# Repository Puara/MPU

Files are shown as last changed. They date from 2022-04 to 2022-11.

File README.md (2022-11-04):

# Media processing Unit (MPU)

The Media Processing Unit, or MPU (former SPU) is the core of the [Puara](https://github.com/Puara) framework: it is responsible to receive sensor data from all connected controllers, mapping devices, and running embedded synthesis processes.

This project is developed and maintained in a partnership between [SAT/Metalab](https://sat.qc.ca/fr/recherche/metalab) and [IDMIL](http://www-new.idmil.org/).

[Media Processing Unit - user guide](./docs/MPU_user_guide.md)

## Building instructions

[Media Processing Unit (MPU) - hardware](./building_instructions_hardware.md)

[Media Processing Unit (MPU) - OS](./building_instructions_os.md)

Alternatively, you can download the MPU OS image to use in any Raspberry Pi.
There's no need to reproduce the hardware of the MPU.

The image can be downloaded in the [Releases](https://gitlab.com/sat-mtl/distribution/rpi-images/-/releases) section](https://gitlab.com/sat-mtl/distribution/rpi-images/-/releases) of the [SAT/Metalab](https://sat.qc.ca/fr/recherche/metalab) maintained [project repository](https://gitlab.com/sat-mtl/distribution/rpi-images).

### More Info

[https://www.edumeneses.com](https://www.edumeneses.com)

[http://www-new.idmil.org/project/guitarami/](http://www-new.idmil.org/project/guitarami/)

## Licensing

The code in this project is licensed under the MIT license, unless otherwise specified within the file.

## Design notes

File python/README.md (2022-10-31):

# MPU LCD + buttons setup (GuitarAMI version)

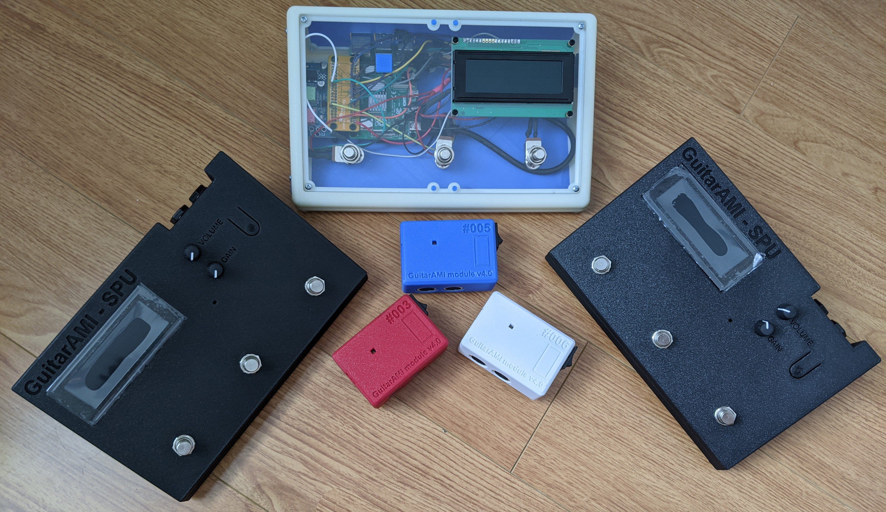
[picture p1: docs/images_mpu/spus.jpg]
MPUs


Instruction on how to build the GuitarAMI MPU can be found in the [Media](./building_instructions_hardware.md) Processing Unit (MPU) - hardware](./building_instructions_hardware.md) guide.

## Set LCD

```bash
sudo apt install python3-rpi.gpio
sudo pip3 install osc4py3
cat <<- "EOF" | sudo tee /lib/systemd/system/lcd.service

[Unit]
Description=OSC to LCD
After=multi-user.target

[Service]
User=mpu
Type=idle
ExecStart=python /home/mpu/sources/MPU/python/lcd.py

[Install]
WantedBy=multi-user.target
EOF
sudo systemctl daemon-reload
sudo systemctl enable --now lcd.service
```

- To send messages to the LCD use `/lcd message 0 0`, sent to port 20000. The first number represents the line and the second the column. Example using oscsend: `oscsend 127.0.0.1 20000 /lcd sii test_message 2 1`
- Sending `/lcd clear 0 0` will clean the LCD

## Set buttons to work

[https://raspberrypihq.com/use-a-push-button-with-raspberry-pi-gpio/](https://raspberrypihq.com/use-a-push-button-with-raspberry-pi-gpio/)

```bash
sudo apt install python3-rpi.gpio python3-gpiozero
sudo pip3 install osc4py3
cat <<- "EOF" | sudo tee /lib/systemd/system/buttonOSC.service
[Unit]
Description=Button to OSC Python3 code
After=multi-user.target

[Service]
User=mpu
Type=idle
ExecStart=python /home/mpu/sources/MPU/python/buttonOSC.py

[Install]
WantedBy=multi-user.target
EOF
sudo systemctl daemon-reload
sudo systemctl enable --now buttonOSC.service
```

## Set status bar

```bash
cat <<- "EOF" | sudo tee /lib/systemd/system/status.service
[Unit]
Description=Status bar OSC Python3 code
After=multi-user.target

[Service]
User=mpu
Type=idle
ExecStart=python /home/mpu/sources/MPU/python/status.py

[Install]
WantedBy=multi-user.target
EOF
sudo systemctl daemon-reload
sudo systemctl enable --now status.service
```

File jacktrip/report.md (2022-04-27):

# JackTrip tests - Brams/IDMIL/uToronto journal

Report in progress used on the JackTrip tests and hardware assembly using the GuitarAMI MPU hardware for the SingWell partnership.

## Schedule

- [X] [First project meeting](#october-14th-2021).
- [X] Duplicate the existing setup (MPU + JackTrip) and automatically set one as a client and another as a server (Oct. 18-22nd, 2021).
- [X] [Latency tests](#october-28th-2021) between the 2 MPUs in a local network on Brams (Oct. 28th, 2021).
- [X] [Latency measurements](#local-network-latency-results) between the 2 MPUs in a local network using jack-delay (Nov. 2nd to 4th, 2021).
- [X] Test internet latency between the 2 MPUs. One MPU will be located at Brams and another at IDMIL (or close location nearby). We will need IT on both universities to fully open UDP communication at port 4464, and we'll probably need to set a VPN between both institutions (TBD, probably Nov. 5th, 2021).
- [X] Define audio interface for the SingWell MPUs ([Focusrite Scarlett Solo](https://focusrite.com/en/audio-interface/scarlett/scarlett-solo)).
- [X] Build 2 MPUs for the project (late November 2021).
- [ ] Final tests at UdeM (second week of December 2021).

## October 14th, 2021

Meeting summary:

- We successfully ran JackTrip on the GuitarAMI Sound Processing Unit (MPU). The MPU acted as a server, and we could connect a laptop also running JackTrip and a client.
- The MPU is capable of serving JackTrip, synthesize sounds, or share audio through the network.
- Start discussing next week the strategies to communicate between UdeM and McGill.

## October 28th, 2021

- Preliminary tests on Brams using two [GuitarAMI MPUs](https://github.com/edumeneses/GuitarAMI/blob/jacktrip/docs/MPU_user_guide.md). Setup worked using a local network, the MPUs, and a laptop used to interact with the machines.

## Local network latency results

- Loopback latency using the built-in interface [Pisound](https://blokas.io/pisound/):
  - Jack configuration: 48000Hz (sample rate), 128 samples (buffer size), 2 period
    - Average latency MPU003: 8.921 ms
    - Average latency MPU005: 8.924 ms

- Latency bettween 2 MPUs (local network) using the built-in interface [Pisound](https://blokas.io/pisound/):
  - Test 1 - Jack configuration: 48000Hz (sample rate), 128 samples (buffer size), 2 period
    - Average latency: 30.256 ms
  - Test 2 - Jack configuration: 96000Hz (sample rate), 128 samples (buffer size), 2 period
    - Average latency: 13.125 ms
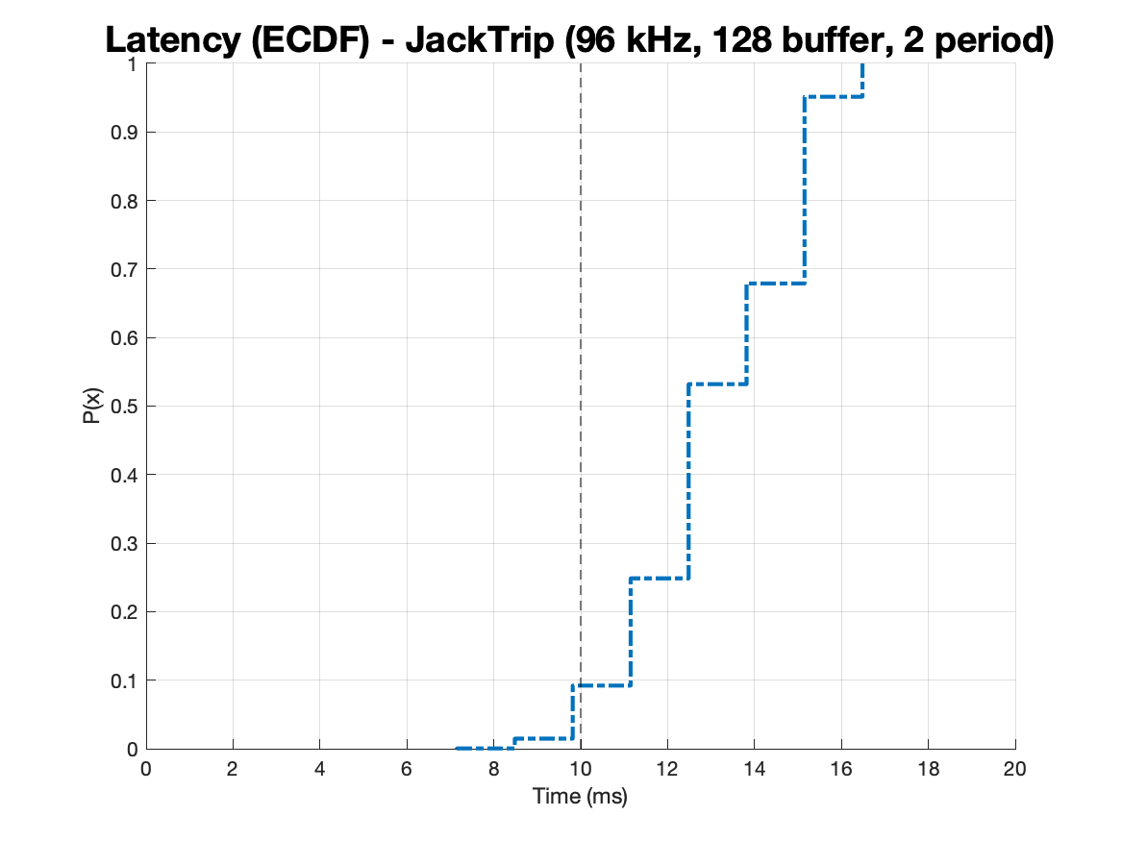
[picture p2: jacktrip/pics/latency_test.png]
Latency (ECDF) - JackTrip (96 kHz, 128 buffer, 2 period)
    - ECDF: 

- Latency bettween 2 MPUs (local network) using the [Presonus AudioBox USB](https://www.presonus.com/products/audiobox-usb) for 48 kHz and [Motu Ultra Lite  mk4](https://motu.com/en-us/news/introducing-the-ultralite-mk4/) for 96 kHz on the client end:
  - Test 3 - Jack configuration: 48000Hz (sample rate), 128 samples (buffer size), 2 period
    - Average latency: 29.645 ms
  - Test 4 - Jack configuration: 96000Hz (sample rate), 128 samples (buffer size), 2 period
    - Average latency: 17.617 ms

Results Summary:

| Description | Sample rate | Average latency |
| --- | --- | --- |
| Loopback | 48 kHz | 8.923 ms |
| JackTrip with Pisound | 48 kHz | 30.256 ms |
| JackTrip with Pisound | 96 kHz | 13.125 ms |
| JackTrip with USB audio | 48 kHz | 29.645 ms |
| JackTrip with USB audio | 96 kHz | 17.617 ms |

## Latency tests with the final JackTrip boxes + Focusrite Scarlett Solo

- Jack configuration: 96000Hz (sample rate), 128 samples (buffer size), 3 period
  - Average latency: 19.366 ms (1859.152 frames)

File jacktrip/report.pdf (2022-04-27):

report.md | 12/3/2021

1 / 2

# JackTrip tests - Brams/IDMIL/uToronto journal

Report in progress used on the JackTrip tests and hardware assembly using the GuitarAMI SPU hardware for the SingWell partnership.

## Schedule

First project meeting.
Duplicate the existing setup (SPU + JackTrip) and automatically set one as a client and another as a server (Oct. 18-22nd, 2021).
Latency tests between the 2 SPUs in a local network on Brams (Oct. 28th, 2021).
Latency measurements between the 2 SPUs in a local network using jack-delay (Nov. 2nd to 4th, 2021).
Test internet latency between the 2 SPUs. One SPU will be located at Brams and another at IDMIL (or close location nearby). We will need IT on both universities to fully open UDP communication at port 4464, and we'll probably need to set a VPN between both institutions (TBD, probably Nov. 5th, 2021).
Define audio interface for the SingWell SPUs (Focusrite Scarlett Solo). (https://focusrite.com/en/audio-interface/scarlett/scarlett-solo)
Build 2 SPUs for the project (late November 2021).
Final tests at UdeM (second week of December 2021).

## October 14th, 2021

Meeting summary:

We successfully ran JackTrip on the GuitarAMI Sound Processing Unit (SPU). The SPU acted as a server, and we could connect a laptop also running JackTrip and a client.
The SPU is capable of serving JackTrip, synthesize sounds, or share audio through the network. Start discussing next week the strategies to communicate between UdeM and McGill.

## October 28th, 2021

Preliminary tests on Brams using two GuitarAMI SPUs. (https://github.com/edumeneses/GuitarAMI/blob/jacktrip/docs/SPU_user_guide.md) Setup worked using a local network, the SPUs, and a laptop used to interact with the machines.

## Local network latency results

Loopback latency using the built-in interface Pisound: (https://blokas.io/pisound/)

Jack configuration: 48000Hz (sample rate), 128 samples (buffer size), 2 period Average latency SPU003: 8.921 ms
Average latency SPU005: 8.924 ms

Latency bettween 2 SPUs (local network) using the built-in interface Pisound: (https://blokas.io/pisound/)

Test 1 - Jack configuration: 48000Hz (sample rate), 128 samples (buffer size), 2 period Average latency: 30.256 ms
Test 2 - Jack configuration: 96000Hz (sample rate), 128 samples (buffer size), 2 period

report.md | 12/3/2021

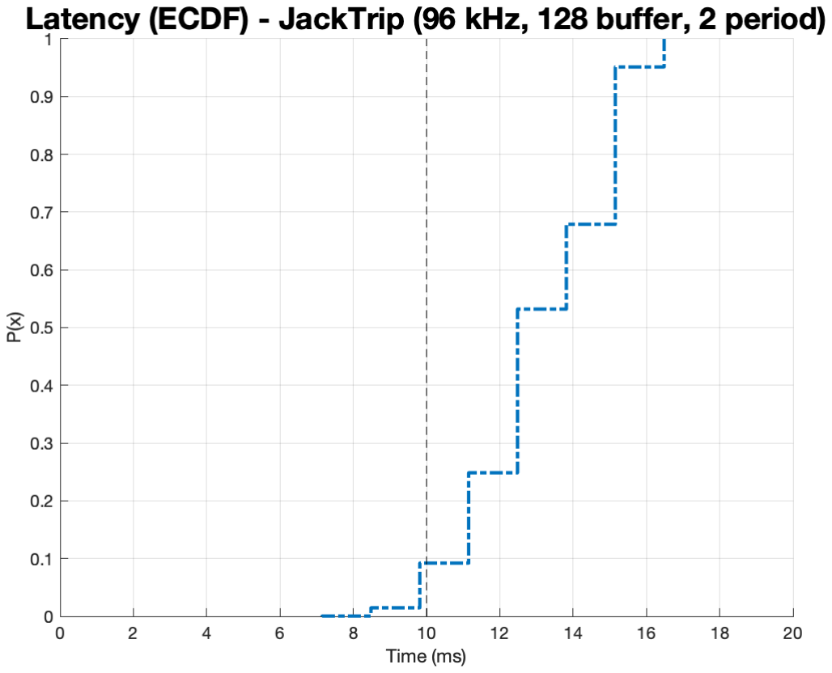
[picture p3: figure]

2 / 2

Average latency: 13.125 ms ECDF:

Latency bettween 2 SPUs (local network) using the Presonus AudioBox USB (https://www.presonus.com/products/audiobox-usb) for 48 kHz and Motu Ultra Lite mk4 for 96 kHz on the client end: (https://motu.com/en-us/news/introducing-the-ultralite-mk4/)

Test 3 - Jack configuration: 48000Hz (sample rate), 128 samples (buffer size), 2 period Average latency: 29.645 ms
Test 4 - Jack configuration: 96000Hz (sample rate), 128 samples (buffer size), 2 period Average latency: 17.617 ms

Results Summary:

Description | Sample rate | Average latency
Loopback | 48 kHz | 8.923 ms
JackTrip with Pisound | 48 kHz | 30.256 ms
JackTrip with Pisound | 96 kHz | 13.125 ms
JackTrip with USB audio | 48 kHz | 29.645 ms
JackTrip with USB audio | 96 kHz | 17.617 ms

## Latency tests with the final JackTrip boxes + Focusrite Scarlett Solo

Jack configuration: 96000Hz (sample rate), 128 samples (buffer size), 3 period
Average latency: 19.366 ms (1859.152 frames)

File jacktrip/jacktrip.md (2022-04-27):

# JackTrip tests on MPU

Official information on building JackTrip on Rpi4 available at [https://help.jacktrip.org/hc/en-us/articles/1500009727561-Build-a-Raspberry-Pi-4B-Computer-with-JackTrip](https://help.jacktrip.org/hc/en-us/articles/1500009727561-Build-a-Raspberry-Pi-4B-Computer-with-JackTrip)

## Compiling and running JackTrip headless on the MPU

- Dependencies: `sudo apt install libjack-jackd2-dev librtaudio-dev qt5-default`
- Extra package to test latency: `sudo apt install -y jack-delay`
- cloning and building JackTrip:

    ```bash
    cd ~/sources
    git clone https://github.com/jacktrip/jacktrip.git
    cd ~/sources/jacktrip/src
    ./build
    export JACK_NO_AUDIO_RESERVATION=1
    ```

## To manually use as a client

- with IP address: `./jacktrip -c [xxx.xx.xxx.xxx]`
- with name: `./jacktrip -c mpuXXX.local`

## Adding a service to start JackTrip server

OBS: client name is the name of the other machine

```bash
cat <<- "EOF" | tee ~/.config/systemd/user/jacktrip_server.service
[Unit]
Description=Run JackTrip server
After=multi-user.target

[Service]
Type=idle
Restart=always
ExecStart=/home/patch/sources/jacktrip/builddir/jacktrip -s --clientname mpu005.local

[Install]
WantedBy=default.target
EOF
```

```bash
sudo chmod 644 ~/.config/systemd/user/jacktrip_server.service
systemctl --user daemon-reload
systemctl --user enable jacktrip_server.service
```

## Adding a service to start JackTrip client (in this example, the server is mpu003.local)

```bash
cat <<- "EOF" | tee ~/.config/systemd/user/jacktrip_client.service
[Unit]
Description=Run JackTrip client
After=multi-user.target

[Service]
Type=idle
Restart=always
ExecStart=/home/patch/sources/jacktrip/builddir/jacktrip -c mpu003.local --clientname mpu005.local

[Install]
WantedBy=default.target
EOF
```

```bash
sudo chmod 644 ~/.config/systemd/user/jacktrip_client.service
systemctl --user daemon-reload
systemctl --user enable jacktrip_client.service
```

## Install aj-snapshot

[http://aj-snapshot.sourceforge.net/](http://aj-snapshot.sourceforge.net/)

Check the last version on the website

```bash
sudo apt install -y libmxml-dev &&\
cd ~/sources &&\
wget http://downloads.sourceforge.net/project/aj-snapshot/aj-snapshot-0.9.9.tar.bz2 &&\
tar -xvjf aj-snapshot-0.9.9.tar.bz2 &&\
cd aj-snapshot-0.9.9 &&\
./configure &&\
make &&\
sudo make install
```

- To create a snapshot: `aj-snapshot -f ~/Documents/default.connections`
- To remove all Jack connections: `aj-snapshot -xj`
- To save connections: `sudo aj-snapshot -f ~/Documents/default.connections`
- To restore connections: `sudo aj-snapshot -r ~/Documents/default.connections`

Set the Jack connections to load at boot:

```bash
cat <<- "EOF" | sudo tee /lib/systemd/system/ajsnapshot.service
[Unit]
Description=AJ-Snapshot
After=sound.target jackaudio.service

[Service]
Type=oneshot
ExecStart=/usr/local/bin/aj-snapshot -r ~/Documents/default.connections

[Install]
WantedBy=multi-user.target
EOF
```

```bash
sudo systemctl daemon-reload &&\
sudo systemctl enable ajsnapshot.service
```

## Mapping using jack in CLI

- Check available devices: `cat /proc/asound/cards`. If you have multiple devices available, can call them by name
- lists jack available ports: `jack_lsp`
- List informtion and connections on ports: `jack_lsp -c` or `jack_lsp -A`
- Connect ports: `jack_connect [ -s | --server servername ] [-h | --help ] port1 port2` (The exit status is zero if successful, 1 otherwise)
- Disconnect ports: `jack_disconnect [ -s | --server servername ] [ -h | --help ] port1 port2`

## Latency tests

Make sure JackTrip is running.

- Connect the necessary audio cable to create a loopback on the audio interface (audio OUT -> audio IN)
- Remove all Jack connections of both machines: `aj-snapshot -xj`
- For the loopback (same interface test): `jack_delay -I system:capture_2 -O system:playback_2`
- For JackTrip (jack_delay running on the server):
  - on the server:
    - `jack_connect system:playback_2 mpu005.local:receive_2`
    - `jack_connect system:capture_2 mpu005.local:send_2`
  - on the client:
    - `jack_connect system:playback_2 mpu003:receive_2`
    - `jack_connect system:capture_2 mpu003:send_2`
- run the test: `jack_delay -O mpu005.local:send_2 -I mpu005.local:receive_2`

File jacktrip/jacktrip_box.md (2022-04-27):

# JackTrip box recipe

- [JackTrip box recipe](#jacktrip-box-recipe)
  - [Hardware](#hardware)
  - [Prepare PatchboxOS](#prepare-patchboxos)
  - [Finish PatchboxOS config](#finish-patchboxos-config)
  - [Compiling and running JackTrip headless on the MPU](#compiling-and-running-jacktrip-headless-on-the-mpu)
  - [To manually use as a client](#to-manually-use-as-a-client)
  - [Adding a service to start JackTrip server](#adding-a-service-to-start-jacktrip-server)
  - [Adding a service to start JackTrip client (in this example, the server is mpu003.local)](#adding-a-service-to-start-jacktrip-client-in-this-example-the-server-is-mpu003local)
  - [Install aj-snapshot](#install-aj-snapshot)
  - [Mapping using jack in CLI](#mapping-using-jack-in-cli)
  - [Latency tests](#latency-tests)
  - [Jack available commands](#jack-available-commands)
  - [Mosquitto MTQQ server (for messaging)](#mosquitto-mtqq-server-for-messaging)
  - [Places to change the MPU name when cloning the SD](#places-to-change-the-mpu-name-when-cloning-the-sd)
  - [Setting the server IP at the client box](#setting-the-server-ip-at-the-client-box)

## Hardware

- Raspberry Pi 4 B with heatsinks and fan (optional)
- Rpi case
- Power supply
- SD card (min 8 GB)
- USB audio interface (recommended: Focusrite Scarlett Solo)

Official information on building JackTrip on Rpi4 is available at [https://help.jacktrip.org/hc/en-us/articles/1500009727561-Build-a-Raspberry-Pi-4B-Computer-with-JackTrip](https://help.jacktrip.org/hc/en-us/articles/1500009727561-Build-a-Raspberry-Pi-4B-Computer-with-JackTrip)

## Prepare PatchboxOS

- Download the [PatchboxOS](https://blokas.io/patchbox-os/#patchbox-os-download)
- Flash the image using [ApplePiBaker](https://www.tweaking4all.com/hardware/raspberry-pi/applepi-baker-v2/), [balenaEtcher](https://www.balena.io/etcher/), or diskutil (dd)
- Connect the audio interface
- Boot the Rpi and folow the [first run tutorial](https://blokas.io/patchbox-os/docs/first-run-options/)
  - ssh to th MPU: `ssh patch@ip_address` (The default user name is *patch* and its password is *blokaslabs*). Use ethernet (wired) connection.
    - update PatchBox
    - set new password: `mappings` or orther password of choice
    - choose default soundcard: USB, 48000, 128, 3
    - select boot: *console*
    - connect to network: *no*
    - choose module: *none*

## Finish PatchboxOS config

- Update system:
  - `sudo apt update`
  - `sudo apt upgrade`
- Enter PiSound configuration: `sudo pisound-config`
  - Update Pisound
  - Change Pisound HotSpot settings:
    - ssid: `jacktrip00X` (use chosen ID)
    - wpa_passphrase: `mappings` (or anothe password of choice)
- Enter Raspi-Config: `sudo raspi-config`
  - Update:
    - `Update this tool to the latest version`
  - System options:
    - Hostname: `jacktrip00X` (use MPU's ID)
  - Advanced options:
    - expand filesystem

Create a place for source codes: `mkdir ~/sources`

Create a place for the user systemd services: `mkdir -p ~/.config/systemd/user`

Reboot

## Compiling and running JackTrip headless on the MPU

- Dependencies: `sudo apt install libjack-jackd2-dev librtaudio-dev qt5-default`
- Extra package to test latency: `sudo apt install -y jack-delay`
- cloning and building JackTrip:

    ```bash
    cd ~/sources
    git clone https://github.com/jacktrip/jacktrip.git
    cd ~/sources/jacktrip
    ./build
    export JACK_NO_AUDIO_RESERVATION=1
    ```

## To manually use as a client

- with IP address: `./jacktrip -c [xxx.xx.xxx.xxx]`
- with name: `./jacktrip -c mpuXXX.local`

## Adding a service to start JackTrip server

OBS: client name is the name of the other machine

```bash
cat <<- "EOF" | tee ~/.config/systemd/user/jacktrip_server.service
[Unit]
Description=Run JackTrip server
After=multi-user.target

[Service]
Type=idle
Restart=always
ExecStart=/home/patch/sources/jacktrip/builddir/jacktrip -s --clientname jacktrip_client

[Install]
WantedBy=default.target
EOF
```

```bash
sudo chmod 644 ~/.config/systemd/user/jacktrip_server.service
systemctl --user daemon-reload
systemctl --user enable jacktrip_server.service
```

## Adding a service to start JackTrip client (in this example, the server is mpu003.local)

Replace the IP address for the server IP.

```bash
cat <<- "EOF" | tee ~/.config/systemd/user/jacktrip_client.service
[Unit]
Description=Run JackTrip client
After=multi-user.target

[Service]
Type=idle
Restart=always
ExecStart=/home/patch/sources/jacktrip/builddir/jacktrip -c 192.168.1.1 --clientname jacktrip_client

[Install]
WantedBy=default.target
EOF
```

```bash
sudo chmod 644 ~/.config/systemd/user/jacktrip_client.service
systemctl --user daemon-reload
```

If you want to enable the client, disable the service and run `systemctl --user enable jacktrip_client.service`

## Install aj-snapshot

[http://aj-snapshot.sourceforge.net/](http://aj-snapshot.sourceforge.net/)

Check the last version on the website

```bash
sudo apt install -y libmxml-dev &&\
cd ~/sources &&\
wget http://downloads.sourceforge.net/project/aj-snapshot/aj-snapshot-0.9.9.tar.bz2 &&\
tar -xvjf aj-snapshot-0.9.9.tar.bz2 &&\
cd aj-snapshot-0.9.9 &&\
./configure &&\
make &&\
sudo make install
```

- To create a snapshot: `aj-snapshot -f ~/Documents/default.connections`
- To remove all Jack connections: `aj-snapshot -xj`
- To save connections: `sudo aj-snapshot -f ~/Documents/default.connections`
- To restore connections: `sudo aj-snapshot -r ~/Documents/default.connections`

Set custom Jack connections to load at boot:

```bash
cat <<- "EOF" | sudo tee /lib/systemd/system/ajsnapshot.service
[Unit]
Description=AJ-Snapshot
After=sound.target jackaudio.service

[Service]
Type=oneshot
ExecStart=/usr/local/bin/aj-snapshot -r ~/Documents/default.connections

[Install]
WantedBy=multi-user.target
EOF
```

```bash
sudo systemctl daemon-reload &&\
sudo systemctl enable ajsnapshot.service
```

## Mapping using jack in CLI

- Check available devices: `cat /proc/asound/cards`. If you have multiple devices available, can call them by name
- lists jack available ports: `jack_lsp`
- List informtion and connections on ports: `jack_lsp -c` or `jack_lsp -A`
- Connect ports: `jack_connect [ -s | --server servername ] [-h | --help ] port1 port2` (The exit status is zero if successful, 1 otherwise)
- Disconnect ports: `jack_disconnect [ -s | --server servername ] [ -h | --help ] port1 port2`

## Latency tests

Make sure JackTrip is running.

- Connect the necessary audio cable to create a loopback on the client's audio interface (audio OUT -> audio IN)
- For the loopback (same interface test): `jack_delay -I system:capture_2 -O system:playback_2`
- run the test: `jack_delay -O jacktrip_client.local:send_2 -I jacktrip_client.local:receive_2`

## Jack available commands

To get a list on the computer, type **jack** and hit *Tab*

|command |command |command |command |command |
|---|---|---|---|---|
| jack_alias | jack_bufsize | jack_capture | jack_capture_gui | jack_connect |
| jackdbus | jack_disconnect | jack-dl | jack-dssi-host | jack_evmon |
| jack_load | jack_lsp | jack_metro | jack_midi_dump | jack_midi_latency_test |
| jack_net_master | jack_net_slave | jack_netsource | jack-osc | jack-play |
| jack_samplerate | jack-scope | jack_server_control | jack_session_notify | jack_showtime |
| jack_thru | jack_transport | jack-transport | jack-udp | jack_unload |
| jack_control | jack_cpu | jack_cpu_load | jackd | jack_wait |
| jack_freewheel  | jack_iodelay | jack-keyboard | jack_latent_client  | jack_midiseq |
| jack_midisine | jack_monitor_client | jack_multiple_metro | jack-plumbing |
| jack-rack | jack_rec | jack-record | jack_test |
| jack_simdtests  | jack_simple_client  | jack_simple_session_client | jack_zombie |

To check Jack logs: `sudo journalctl -u jack.service`

## Mosquitto MTQQ server (for messaging)

Install Mosquitto: `sudo apt install -y mosquitto mosquitto-clients`

Set both client and server to listen to the server's broker: `mosquitto_sub -h jacktrip001.local -t message`

Send periodic messages from each machine:

```bash
cat <<- "EOF" | sudo tee /etc/systemd/system/ping.service
[Unit]
Description=Service for sending ping MTQQ messages
Wants=ping.timer

[Service]
Type=oneshot
ExecStart=sh -c 'mosquitto_pub -h "jacktrip001.local" -t "message" -m "Jacktrip001 is up"'

[Install]
WantedBy=multi-user.target
EOF
```

```bash
cat <<- "EOF" | sudo tee /etc/systemd/system/ping.timer
[Unit]
Description=Service for sending ping MTQQ messages
Requires=ping.service

[Timer]
Unit=ping.service
OnUnitInactiveSec=1s
AccuracySec=1s

[Install]
WantedBy=timers.target
EOF
```

Enable timer

```bash
sudo systemctl daemon-reload
sudo systemctl enable ping.timer
```

## Places to change the MPU name when cloning the SD

- Enter PiSound configuration: `sudo pisound-config`
  - Change Pisound HotSpot settings:
    - ssid: `jacktrip00X` (use MPU's ID)
- Enter Raspi-Config: `sudo raspi-config`
  - System options:
    - Hostname: `jacktrip00X` (use chosen ID)

## Setting the server IP at the client box

- Edit the *jacktrip_client.service* file: `nano ~/.config/systemd/user/jacktrip_client.service`
- Replace the IP at the line `ExecStart=/home/patch/sources/jacktrip/builddir/jacktrip -c 192.168.1.1 --clientname jacktrip_client` for the new IP address
- Save the file (Ctrl+O, then hit ENTER in *nano*) and exit (Ctrl+X in *nano*).
- Edit the *ping.service* file: `sudo nano /etc/systemd/system/ping.service`
- Replace the IP (server name) and the client box name at the line `ExecStart=sh -c 'mosquitto_pub -h "jacktrip001.local" -t "message" -m "Jacktrip002 is up"` for the new IP address and proper client name.
- Save the file (Ctrl+O, then hit ENTER in *nano*) and exit (Ctrl+X in *nano*).
- Update the systemctl daemons: `systemctl --user daemon-reload` and `sudo systemctl daemon-reload`
- Restart the services: `systemctl --user restart jacktrip_client.service` and `sudo systemctl restart ping.timer`
- To check connection (if the server is available and accessible through the given IP): `systemctl --user status jacktrip_client.service`

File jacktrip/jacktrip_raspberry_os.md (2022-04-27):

# JackTrip tests on Raspberry OS

Using Rpi 4B + Raspbian OS + Pisound or USB audio Interface

Official information on building JackTrip on Rpi4 available at [https://help.jacktrip.org/hc/en-us/articles/1500009727561-Build-a-Raspberry-Pi-4B-Computer-with-JackTrip](https://help.jacktrip.org/hc/en-us/articles/1500009727561-Build-a-Raspberry-Pi-4B-Computer-with-JackTrip)

## Prepare SD card

- Download [Raspberry OS](https://www.raspberrypi.com/software/)
- Flash the image using [ApplePiBaker](https://www.tweaking4all.com/hardware/raspberry-pi/applepi-baker-v2/), [balenaEtcher](https://www.balena.io/etcher/), or diskutil (dd)
- Create an ssh file at the SSD boot folder: `touch ssh`
- Create a `wpa_supplicant.conf` file with the following contents (change SSID and password!) and boot the system (Rpi)

    ```bash
    cat <<EOF >wpa_supplicant.conf
        ctrl_interface=DIR=/var/run/wpa_supplicant GROUP=netdev
        update_config=1
        country=CA

        network={
            ssid="your_real_wifi_ssid"
            scan_ssid=1
            psk="your_real_password"
            key_mgmt=WPA-PSK
        }
    EOF
    ```

## First config

- ssh to the Rpi: `ssh pi@ip_address` (The default user name is *pi* and its password is *raspberry*)
- Run `sudo raspi-config`
  - Update
  - Change password (mappings)
  - Change hostmane (MPU001)
  - Set WiFi Country (in system options, Wireless LAN)
  - Set locale (en_CA UTF-8 UTF-8)
  - Set timezone
  - Expand filesystem
- reboot
- Update the system:
  - `sudo apt update`
  - `sudo apt dist-upgrade`
- Install Vim as an optional editor: `sudo apt -y install vim`
- Create some folders: `mkdir ~/sources ~/Documents ~/.config/systemd/ ~/.config/systemd/user`

## Install Jack2

[http://jackaudio.org/faq/build_info.html](http://jackaudio.org/faq/build_info.html)

- Dependencies:
  
  `sudo apt-get install libsamplerate0-dev libsndfile1-dev libasound2-dev libavahi-client-dev libreadline-dev libfftw3-dev libudev-dev libncurses5-dev cmake git`

- compile and install jackd (no d-bus):

    ```bash
    cd ~/sources
    git clone git://github.com/jackaudio/jack2 --depth 1
    cd ~/sources/jack2
    ./waf configure --alsa --libdir=/usr/lib/arm-linux-gnueabihf/
    ./waf build
    sudo ./waf install
    sudo ldconfig
    sudo sh -c "echo @audio - memlock 256000 >> /etc/security/limits.conf"
    sudo sh -c "echo @audio - rtprio 75 >> /etc/security/limits.conf"
    echo /usr/local/bin/jackd -P50 -dalsa -p128 -n2 -r48000 > ~/.jackdrc
    ```

- set Jack to start at boot:

    ```bash
    cat <<- "EOF" | sudo tee /lib/systemd/system/jackaudio.service
    [Unit]
    Description=JACK Audio
    After=sound.target

    [Service]
    ExecStart=jackd -P50 -t2000 -d alsa -d hw:USB -p128 -n2 -r48000 -s &

    [Install]
    WantedBy=multi-user.target
    EOF

    ```

    ```bash
    sudo chmod 644 /lib/systemd/system/jackaudio.service
    sudo systemctl daemon-reload
    sudo systemctl enable jackaudio.service
    sudo systemctl start jackaudio.service
    ```

- Reboot

Some commands:

- Check available devices: `cat /proc/asound/cards`. If you have multiple devices available, can call them by name
- List informtion and connections on ports: `jack_lsp -c`
- Connect ports: `jack_connect [ -s | --server servername ] [-h | --help ] port1 port2` (The exit status is zero if successful, 1 otherwise)
- Disconnect ports: `jack_disconnect [ -s | --server servername ] [ -h | --help ] port1 port2`

## Compiling and running JackTrip headless on the MPU

- Dependencies: `sudo apt install libjack-jackd2-dev librtaudio-dev qt5-default`
- Extra package to test latency: `sudo apt install jack-delay`
- cloning and building JackTrip:

    ```bash
    cd ~/sources
    git clone https://github.com/jacktrip/jacktrip.git
    cd ~/sources/jacktrip/src
    ./build
    export JACK_NO_AUDIO_RESERVATION=1
    ```

## To manually use as a client

- with IP address: `./jacktrip -c [xxx.xx.xxx.xxx]`
- with name: `./jacktrip -c mpuXXX.local`

## Adding a service to start JackTrip server

```bash
cat <<- "EOF" | sudo tee /lib/systemd/system/jacktrip_server.service
[Unit]
Description=Run JackTrip server
After=multi-user.target

[Service]
Type=idle
Restart=always
ExecStart=/home/pi/sources/jacktrip/builddir/jacktrip -s

[Install]
WantedBy=multi-user.target
EOF
```

```bash
sudo chmod 644 /lib/systemd/system/jacktrip_server.service
sudo systemctl daemon-reload
sudo systemctl enable jacktrip_server.service
sudo systemctl start jacktrip_server.service
```

## Adding a service to start JackTrip client (in this example, the server is mpu003.local)

```bash
cat <<- "EOF" | sudo tee /lib/systemd/system/jacktrip_client.service
[Unit]
Description=Run JackTrip client
After=multi-user.target

[Service]
Type=idle
Restart=always
ExecStart=/home/pi/sources/jacktrip/builddir/jacktrip -c mpu005.local

[Install]
WantedBy=multi-user.target
EOF
```

```bash
sudo chmod 644 /lib/systemd/system/jacktrip_client.service
sudo systemctl daemon-reload
sudo systemctl enable jacktrip_client.service
sudo systemctl start jacktrip_client.service
```

## Mapping using jack in CLI

- `jack_lsp`: lists jack available ports
- `jack_lsp -c`: lists jack available ports with connections

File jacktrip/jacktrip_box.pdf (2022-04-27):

jacktrip_box.md | 12/3/2021

# JackTrip box recipe

Hardware Prepare PatchboxOS Finish PatchboxOS config Compiling and running JackTrip headless on the SPU To manually use as a client Adding a service to start JackTrip server Adding a service to start JackTrip client (in this example, the server is spu003.local) Install aj-snapshot Mapping using jack in CLI Latency tests Jack available commands Places to change the SPU name when cloning the SD Setting the server IP at the client box

## Hardware

Raspberry Pi 4 B with heatsinks and fan (optional)
Rpi case
Power supply
SD card (min 8 GB)
USB audio interface (recommended: Focusrite Scarlett Solo)

Official information on building JackTrip on Rpi4 available at https://help.jacktrip.org/hc/en-us/articles/1500009727561-Build-a-Raspberry-Pi-4B-Computer-with-JackTrip (https://help.jacktrip.org/hc/en-us/articles/1500009727561-Build-a-Raspberry-Pi-4B-Computer-with-JackTrip)

## Prepare PatchboxOS

Download the PatchboxOS (https://blokas.io/patchbox-os/#patchbox-os-download)
Flash the image using ApplePiBaker, (https://www.tweaking4all.com/hardware/raspberry-pi/applepi-baker-v2/) balenaEtcher, (https://www.balena.io/etcher/) or diskutil (dd)
Connect the audio interface
Boot the Rpi and folow the first run tutorial (https://blokas.io/patchbox-os/docs/first-run-options/)
ssh to th SPU: ssh patch@ip_address (The default user name is patch and its password is blokaslabs). Use ethernet (wired) connection.
update PatchBox
set new password: mappings or orther password of choice
choose default soundcard: USB, 48000, 128, 3
select boot: console
connect to network: no
choose module: none

## Finish PatchboxOS config

Update system:
sudo apt update
sudo apt upgrade
Enter PiSound configuration: sudo pisound-config Update Pisound
Change Pisound HotSpot settings:
ssid: jacktrip00X (use chosen ID)
wpa_passphrase: mappings (or anothe password of choice) Enter Raspi-Config: sudo raspi-config Update:
Update this tool to the latest version System options:
Hostname: jacktrip00X (use SPU's ID) Advanced options:
expand filesystem

Create a place for source codes: mkdir ~/sources

Create a place for the user systemd services: mkdir -p ~/.config/systemd/user

Reboot

## Compiling and running JackTrip headless on the SPU

Dependencies: sudo apt install libjack-jackd2-dev librtaudio-dev qt5-default

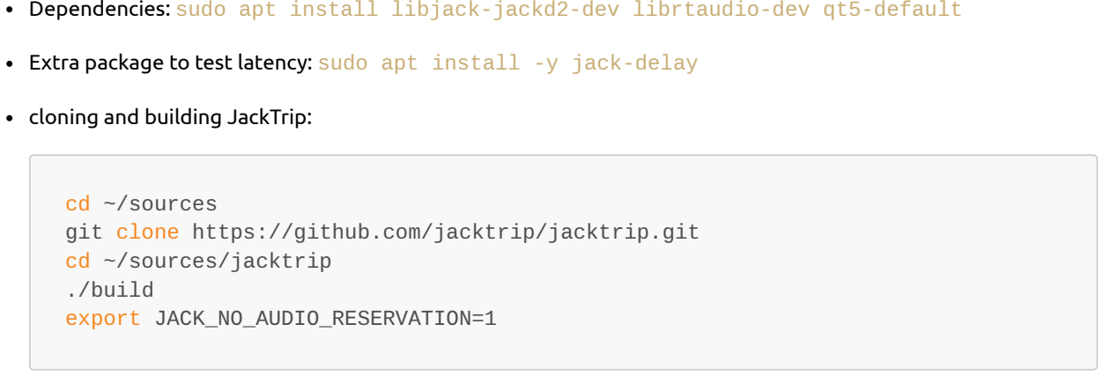
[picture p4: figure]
cloning and building JackTrip:; cd ~/sources git clone https://github.com/jacktrip/jacktrip.git cd ~/sources/jacktrip ./build export JACK_NO_AUDIO_RESERVATION=1

Extra package to test latency: sudo apt install -y jack-delay

## To manually use as a client

with IP address: ./jacktrip -c [xxx.xx.xxx.xxx] with name: ./jacktrip -c spuXXX.local

## Adding a service to start JackTrip server

OBS: client name is the name of the other machine

cat <<- "EOF" | tee ~/.config/systemd/user/jacktrip_server.service
[Unit]
Description=Run JackTrip server
After=multi-user.target

[Service]
Type=idle
Restart=always
ExecStart=/home/patch/sources/jacktrip/builddir/jacktrip -s --clientname jacktrip_client

[Install]
WantedBy=default.target
EOF

sudo chmod 644 ~/.config/systemd/user/jacktrip_server.service systemctl --user daemon-reload
systemctl --user enable jacktrip_server.service

## Adding a service to start JackTrip client (in this example, the server is spu003.local)

Replace the IP address for the server IP.

cat <<- "EOF" | tee ~/.config/systemd/user/jacktrip_client.service
[Unit]
Description=Run JackTrip client
After=multi-user.target

[Service]
Type=idle
Restart=always
ExecStart=/home/patch/sources/jacktrip/builddir/jacktrip -c 192.168.1.1 --clientname jacktrip_client

[Install]
WantedBy=default.target
EOF

If you want to enable the client, disable the service and run systemctl --user enable jacktrip_client.service

## Install aj-snapshot

http://aj-snapshot.sourceforge.net/

Check the last version on the website

sudo apt install -y libmxml-dev &&\
cd ~/sources &&\
wget http://downloads.sourceforge.net/project/aj-snapshot/aj-snapshot-0.9.9.tar.bz2&&\
tar -xvjf aj-snapshot-0.9.9.tar.bz2 &&\
cd aj-snapshot-0.9.9 &&\
./configure &&\
make &&\
sudo make install

To create a snapshot: aj-snapshot -f ~/Documents/default.connections
To remove all Jack connections: aj-snapshot -xj
To save connections: sudo aj-snapshot -f ~/Documents/default.connections To restore connections: sudo aj-snapshot -r ~/Documents/default.connections

Set custom Jack connections to load at boot:

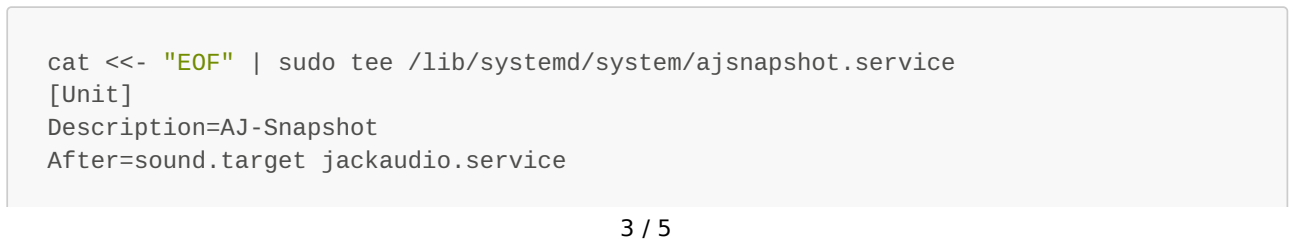
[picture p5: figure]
[Unit] Description=AJ-Snapshot After=sound.target jackaudio.service

cat <<- "EOF" | sudo tee /lib/systemd/system/ajsnapshot.service

[Service]
Type=oneshot
ExecStart=/usr/local/bin/aj-snapshot -r ~/Documents/default.connections

[Install]
WantedBy=multi-user.target
EOF

sudo systemctl daemon-reload &&\
sudo systemctl enable ajsnapshot.service

## Mapping using jack in CLI

Check available devices: cat /proc/asound/cards. If you have multiple devices available, can call them by name
lists jack available ports: jack_lsp
List informtion and connections on ports: jack_lsp -c or jack_lsp -A
Connect ports: jack_connect [ -s | --server servername ] [-h | --help ] port1 port2 (The
exit status is zero if successful, 1 otherwise)
Disconnect ports: jack_disconnect [ -s | --server servername ] [ -h | --help ] port1
port2

## Latency tests

Make sure JackTrip is running.

Connect the necessary audio cable to create a loopback on the client's audio interface (audio OUT -> audio IN) For the loopback (same interface test): jack_delay -I system:capture_2 -O system:playback_2 run the test: jack_delay -O jacktrip_client.local:send_2 -I jacktrip_client.local:receive_2

## Jack available commands

To get a list on the computer type jack and hit Tab

command | command | command | command | command
jack_alias | jack_bufsize | jack_capture | jack_capture_gui | jack_connect
jackdbus | jack_disconnect | jack-dl | jack-dssi-host | jack_evmon
jack_load | jack_lsp | jack_metro | jack_midi_dump | jack_midi_latency_test
jack_net_master | jack_net_slave | jack_netsource | jack-osc | jack-play
jack_samplerate | jack-scope | jack_server_control | jack_session_notify | jack_showtime
jack_thru | jack_transport | jack-transport | jack-udp | jack_unload
jack_control | jack_cpu | jack_cpu_load | jackd | jack_wait
jack_freewheel | jack_iodelay | jack-keyboard | jack_latent_client | jack_midiseq
jack_midisine | jack_monitor_client | jack_multiple_metro | jack-plumbing

command | command | command | command | command
jack-rack | jack_rec | jack-record | jack_test
jack_simdtests | jack_simple_client | jack_simple_session_client | jack_zombie

To check Jack logs: sudo journalctl -u jack.service

## Places to change the SPU name when cloning the SD

Enter PiSound configuration: sudo pisound-config
Change Pisound HotSpot settings:
ssid: jacktrip00X (use SPU's ID)
Enter Raspi-Config: sudo raspi-config
| System options:
Hostname: jacktrip00X (use chosen ID)

## Setting the server IP at the client box

Edit the jacktrip_client.service file: nano ~/.config/systemd/user/jacktrip_client.service Replace the IP at the line ExecStart=/home/patch/sources/jacktrip/builddir/jacktrip -c 192.168.1.1 --clientname jacktrip_client for the new IP address
Save the file (Ctrl+O, then hit ENTER in nano) and exit (Ctrl+X in nano).
Update the systemctl daemon: systemctl --user daemon-reload
Restart the service: systemctl --user restart jacktrip_client.service
To check connection (if the server is availalbe and accessible through the given IP): systemctl --user status jacktrip_client.service

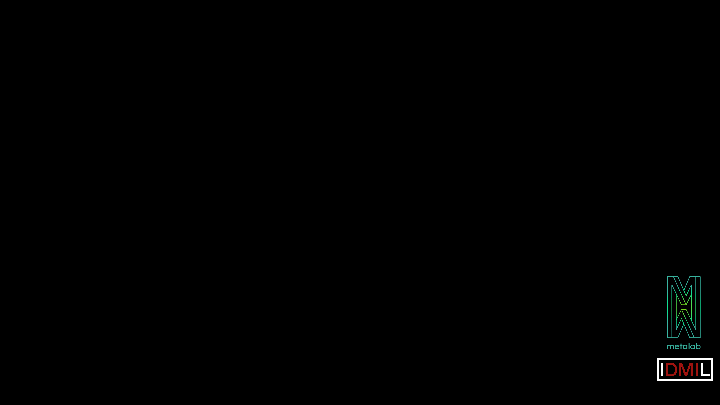
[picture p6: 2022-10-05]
wallpaper.png

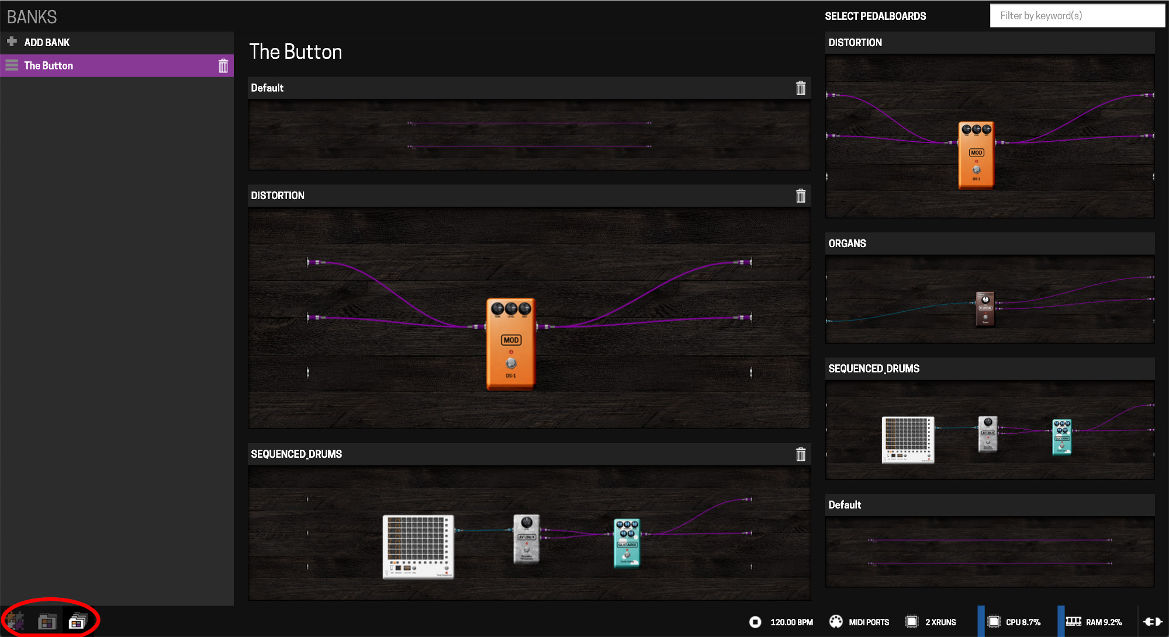
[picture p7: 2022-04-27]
docs/images_mpu/pedalboards.jpg

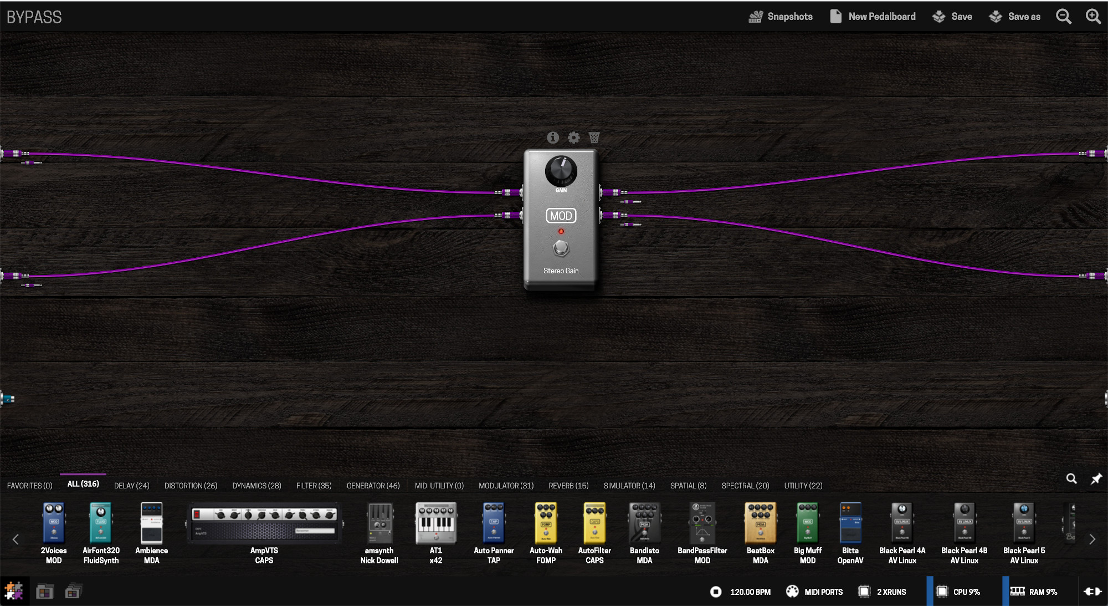
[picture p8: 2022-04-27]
docs/images_mpu/plugin_host.jpg

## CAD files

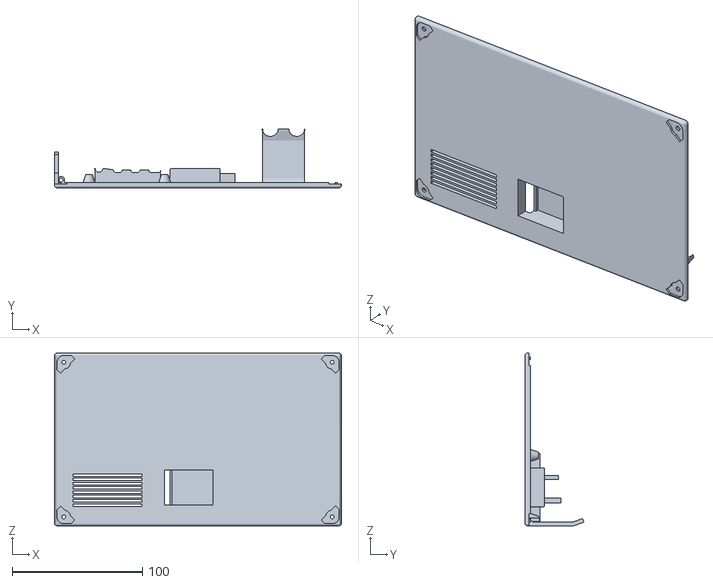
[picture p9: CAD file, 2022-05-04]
3D_printed_enclosure/SPU_box v5 - Bottom.stl
220.0 x 45.2 x 132.5

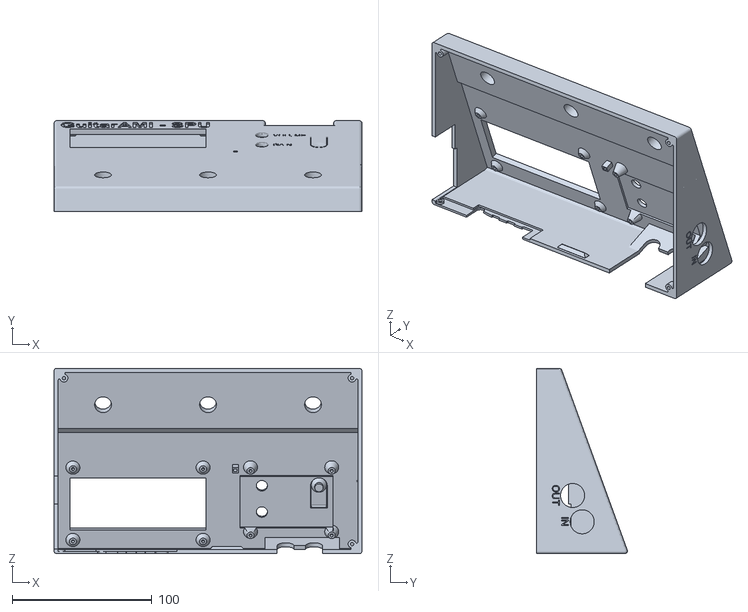
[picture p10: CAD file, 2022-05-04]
3D_printed_enclosure/SPU_box v5 - Top.stl
220.0 x 64.9 x 132.5

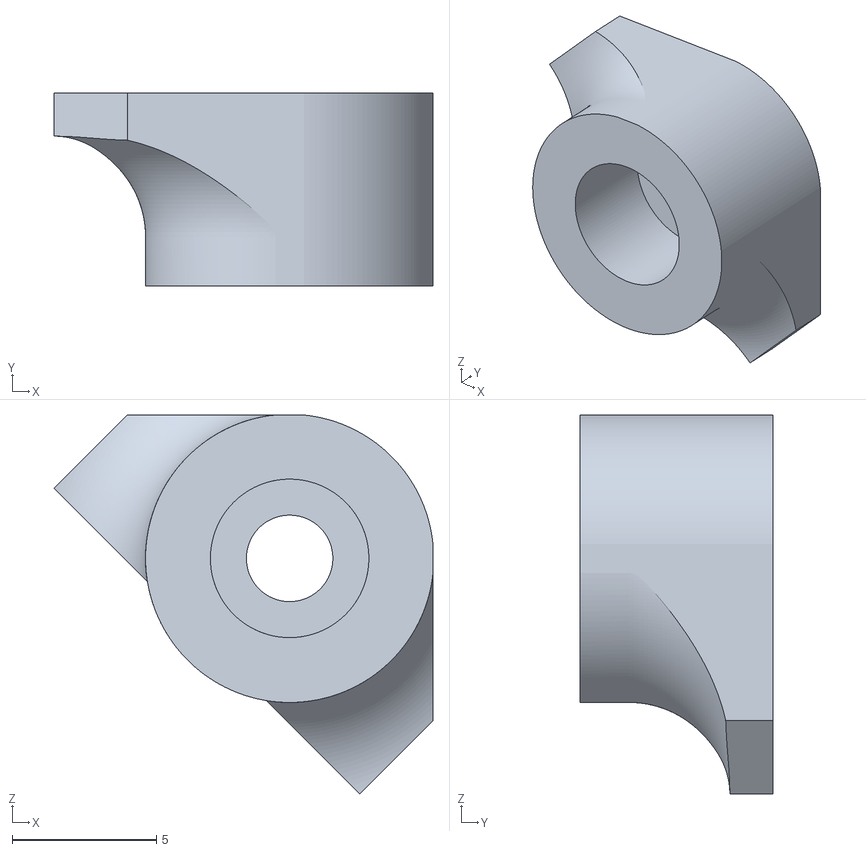
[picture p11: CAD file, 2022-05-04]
3D_printed_enclosure/SPU_box v5 - feet.stl
13.2 x 6.70 x 13.2

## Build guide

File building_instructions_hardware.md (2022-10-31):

# Hardware building instructions (GuitarAMI MPU)

- [Hardware building instructions (GuitarAMI MPU)](#hardware-building-instructions-guitarami-mpu)
  - [BOM](#bom)
  - [Connections](#connections)
    - [Fe-Pi](#fe-pi)
    - [Pisound](#pisound)
  - [Instructions](#instructions)

## BOM

| Qty | Description | Online Reference |
| --- |:---|:--- |
| 3 | Pro-Grade SPST Momentary Foot Switch - Normally Open | https://lovemyswitches.com/pro-grade-spst-momentary-foot-switch-normally-open-soft-touch-solder-lug/ |
| 1 | RGB backlight negative LCD 20x4 | https://www.adafruit.com/product/498#description |
| 1 | USB C Round Panel Mount Extension Cable - 30cm | https://www.adafruit.com/product/4218 |
| 1 | Pimoroni Pico HAT Hacker | https://www.adafruit.com/product/3577 |
| 1 | Stacking Header for Pi | https://www.adafruit.com/product/1979 |
| 8 | PAN PHILLIPS SCREW, M2.5 X 4.5 T | https://www.digikey.ca/en/products/detail/essentra-components/50M025045P008/11638585 |
| 1 | Pisound | https://blokas.io/pisound/ |
| 1 | Raspberry Pi 4 Model B/4GB + SD + Power + heatsinks  | https://www.buyapi.ca/product/raspberry-pi-4-model-b-4gb/ |
| 1 | Male to Female GPIO Ribbon Cable | https://www.buyapi.ca/product/male-to-female-gpio-ribbon-cable/ |
| 1 | 3D print filament -  PLA 1.75mm | https://filaments.ca/ |

## Connections

### Fe-Pi

| Raspberry Pi 4B | LCD | pot | switch 1 | switch 2 | switch 3 |
| --- | --- | --- | --- | --- | --- |
| Pin 1, 3v3 | | | | | |
| Pin 2, 5V | 2 | right  | | | |
| Pin 3, I2C.1_SDA  | | | | | |
| Pin 4, 5V | | | | | |
| Pin 5, I2C.1_SCL  | | | | | |
| Pin 6, Ground | 1, 5, 16 | left | left | left | left |
| Pin 7, GPIO 4 | | | | | |
| Pin 8, GPIO 14 | | | | | |
| Pin 9, Ground | | | | | |
| Pin 10, GPIO 15 | 6 | | | | |
| Pin 11, GPIO 17 | 14 | | | | |
| Pin 12, GPIO 18 | | | | | |
| Pin 13, GPIO 27 | | | right | | |
| Pin 14, Ground | | | | | |
| Pin 15, GPIO 22 | | | | right | |
| Pin 16, GPIO 23 | 13 | | | | |
| Pin 17, 3v3 | 15 | | | | |
| Pin 18, GPIO 24 | 12 | | | | |
| Pin 19, GPIO 10 | | | | | |
| Pin 20, Ground | | | | | |
| Pin 21, GPIO 9 | | | | | |
| Pin 22, GPIO 25 | 11 | | | | |
| Pin 23, GPIO 11 | | | | | |
| Pin 24, GPIO 8 | | | | | |
| Pin 25, Ground | | | | | |
| Pin 26, GPIO 7 | 4 | | | | |
| Pin 27, I2C.0_SDA | | | | | |
| Pin 28, I2C.0_SCL | | | | | |
| Pin 29, GPIO 5 | | | | | right |
| Pin 30, Ground | | | | | |
| Pin 31, GPIO 6 | | | | | |
| Pin 32, GPIO 12 | | | | | |
| Pin 33, GPIO 13 | | | | | |
| Pin 34, Ground | | | | | |
| Pin 35, GPIO 19 | | | | | |
| Pin 36, GPIO 16 | | | | | |
| Pin 37, GPIO 26 | | | | | |
| Pin 38, GPIO 20 | | | | | |
| Pin 39, Ground | | | | | |
| Pin 40, GPIO 21 | | | | | |
| | 3 | middle | | | |

- The audio interface is connected by the ribbon cable

### Pisound

| Raspberry Pi 4B | LCD | pot | switch 1 | switch 2 | switch 3 | PiSound | Color  |
| --- | --- | --- | --- | --- | --- |:---:|:--- |
| Pin 1, 3v3 | 15 | | | | | | orange |
| Pin 2, 5V | 2 | right  | | | | | red |
| Pin 3, GPIO 2 | 6 | | | | | | yellow |
| Pin 4, 5V | | | | | | | |
| Pin 5, GPIO 3 | 11 | | | | | | green  |
| Pin 6, Ground | 1, 5, 16 | left | | | | | black  |
| Pin 7, GPIO 4 | 14 | | | | | | blue |
| Pin 8, GPIO 14 | 12 | | | | | | purple |
| Pin 9, Ground | | | | | | | |
| Pin 10, GPIO 15 | | | | | | | |
| Pin 11, GPIO 17 | | | | | | X | |
| Pin 12, GPIO 18 | | | | | | X | |
| Pin 13, GPIO 27 | | | right | | | | white  |
| Pin 14, Ground | | | | | | | |
| Pin 15, GPIO 22 | | | | right | | | gray |
| Pin 16, GPIO 23 | 13 | | | | | | brown  |
| Pin 17, 3v3 | | | | | | | |
| Pin 18, GPIO 24 | | | | | | X | |
| Pin 19, GPIO 10 | | | | | | X | |
| Pin 20, Ground | | | left | left | left | | black  |
| Pin 21, GPIO 9 | | | | | | X | |
| Pin 22, GPIO 25 | | | | | | X | |
| Pin 23, GPIO 11 | | | | | | X | |
| Pin 24, GPIO 8 | | | | | | X | |
| Pin 25, Ground | | | | | | | |
| Pin 26, GPIO 7 | 4 | | | | | | white  |
| Pin 27, GPIO 0 | | | | | | | |
| Pin 28, GPIO 1 | | | | | | | |
| Pin 29, GPIO 5 | | | | | right | | blue |
| Pin 30, Ground | | | | | | | |
| Pin 31, GPIO 6 | | | | | | X | |
| Pin 32, GPIO 12 | | | | | | X | |
| Pin 33, GPIO 13 | | | | | | X | |
| Pin 34, Ground | | | | | | | |
| Pin 35, GPIO 19 | | | | | | X | |
| Pin 36, GPIO 16 | | | | | | X | |
| Pin 37, GPIO 26 | | | | | | X | |
| Pin 38, GPIO 20 | | | | | | X | |
| Pin 39, Ground | | | | | | | |
| Pin 40, GPIO 21 | | | | | | X | |
| | 3 | middle | | | | | gray |

- The audio interface is connected by the ribbon cable

## Instructions

Start by 3D printing the enclosure and arrange the parts:

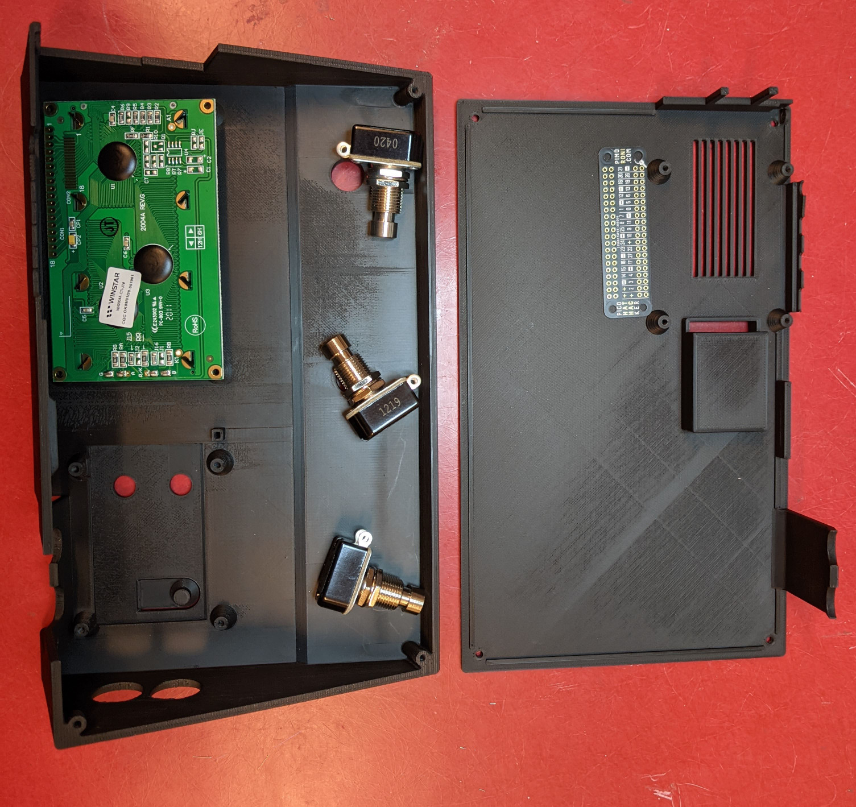
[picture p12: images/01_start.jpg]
Start


Solder the long female header pins to the Pimoroni Pico HAT Hacker:

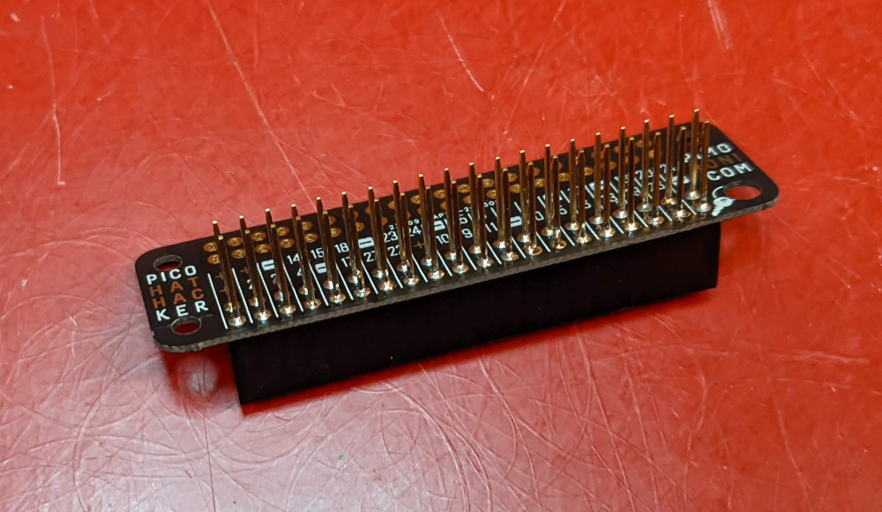
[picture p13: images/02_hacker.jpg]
Pimoroni Pico HAT Hacker


Solder the wires according to the table above.

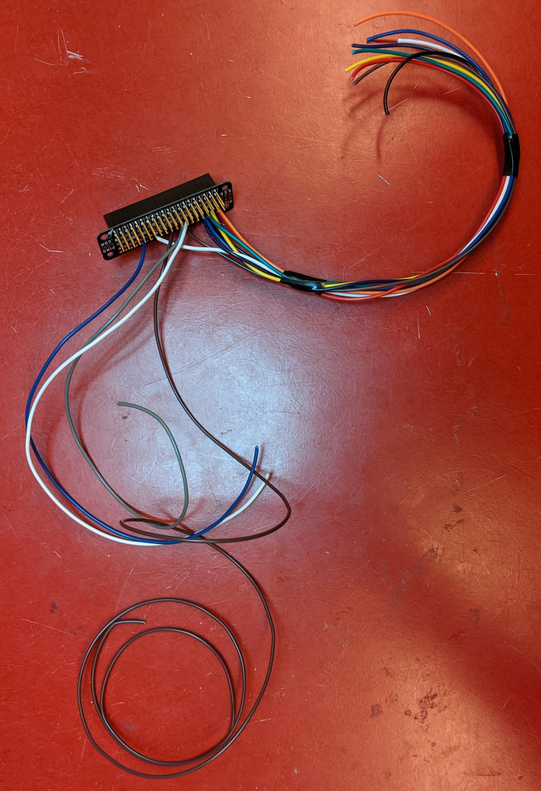
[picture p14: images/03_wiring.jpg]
Wiring


Also, solder the potentiometer used to control the LCD backlight intensity:

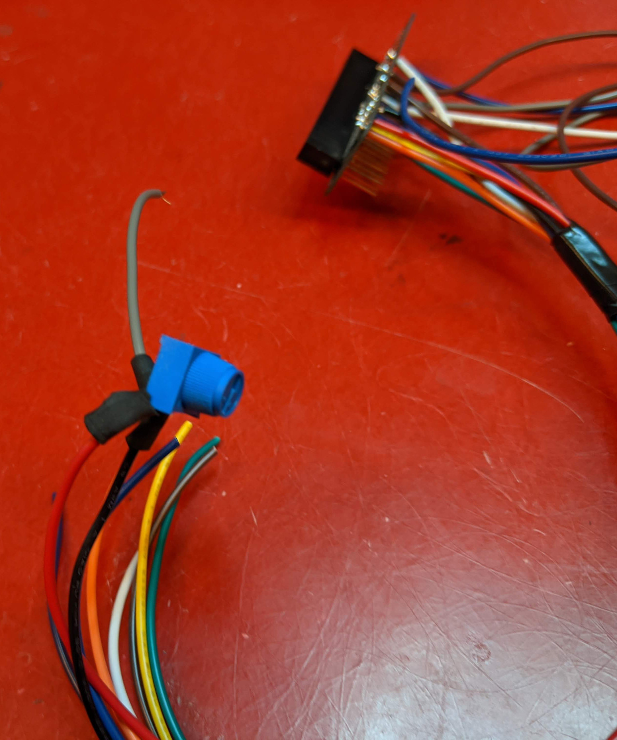
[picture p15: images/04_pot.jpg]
Pot


Solder the wires on the LCD:

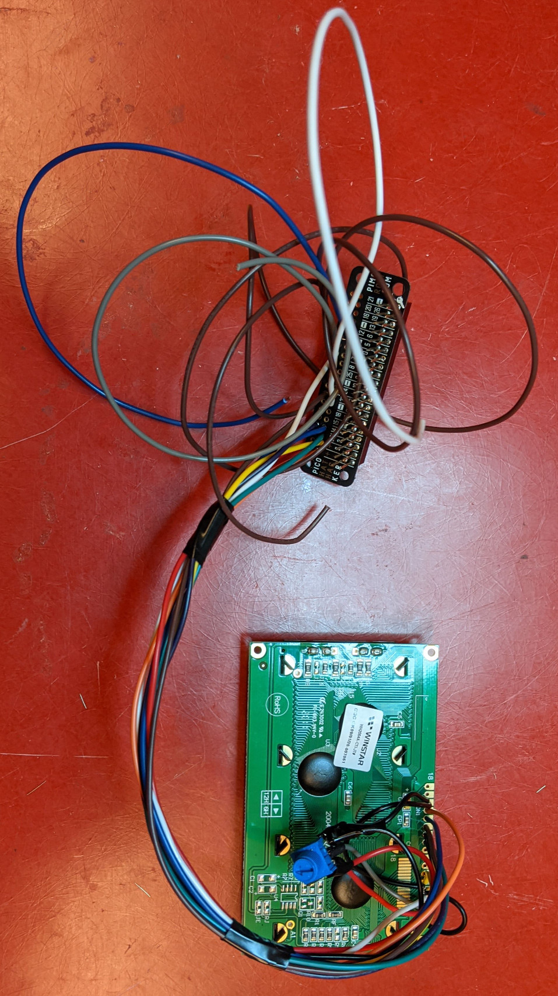
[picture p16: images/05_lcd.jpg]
LCD


Solder the footswitches and prepare to assemble everything together:

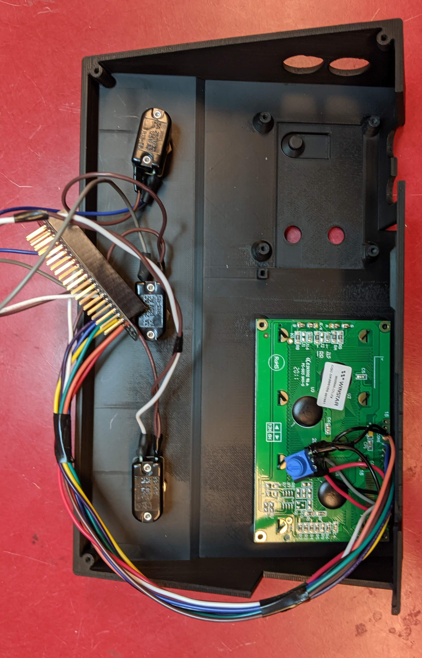
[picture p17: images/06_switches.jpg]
Footswitches


The riboon cable needs the cape off to fit the enclosure:

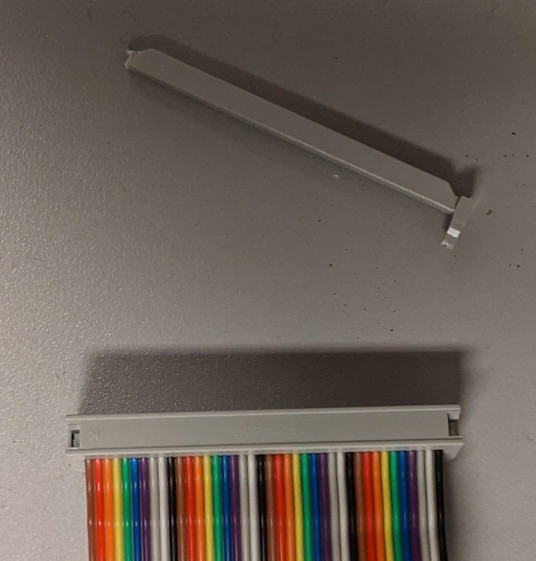
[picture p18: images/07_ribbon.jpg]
Ribbon


The Raspberry Pi can now be secured with M2.5 screws.
The ribbon cable and the Hat Hacker are connected as shown below:

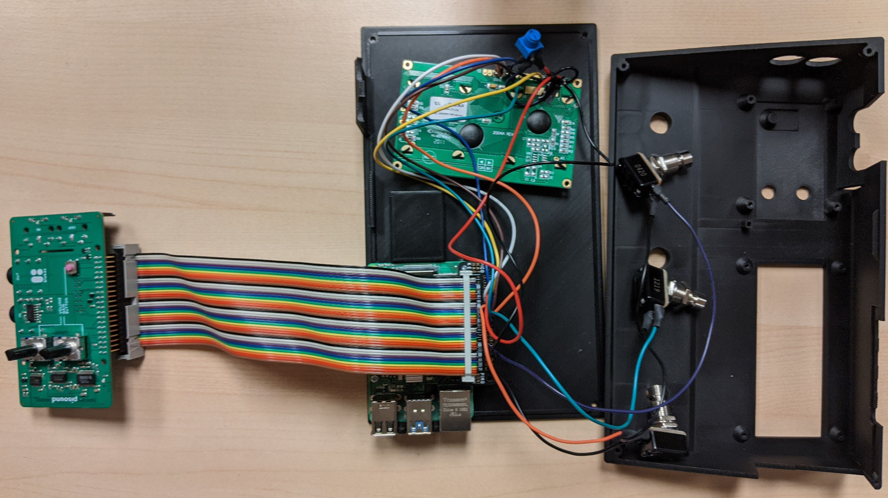
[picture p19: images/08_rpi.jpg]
Raspberry Pi! Raspberry Pi


The LCD and Pisound can be secured with screws now.

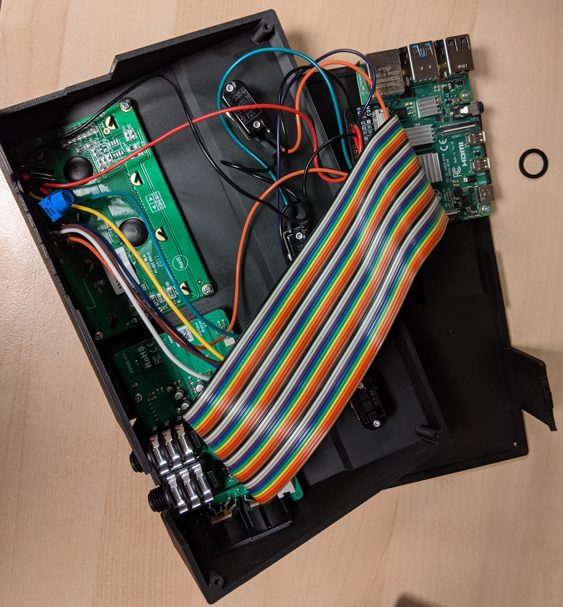
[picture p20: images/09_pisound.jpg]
PiSound


Close the enclosure and we're done.

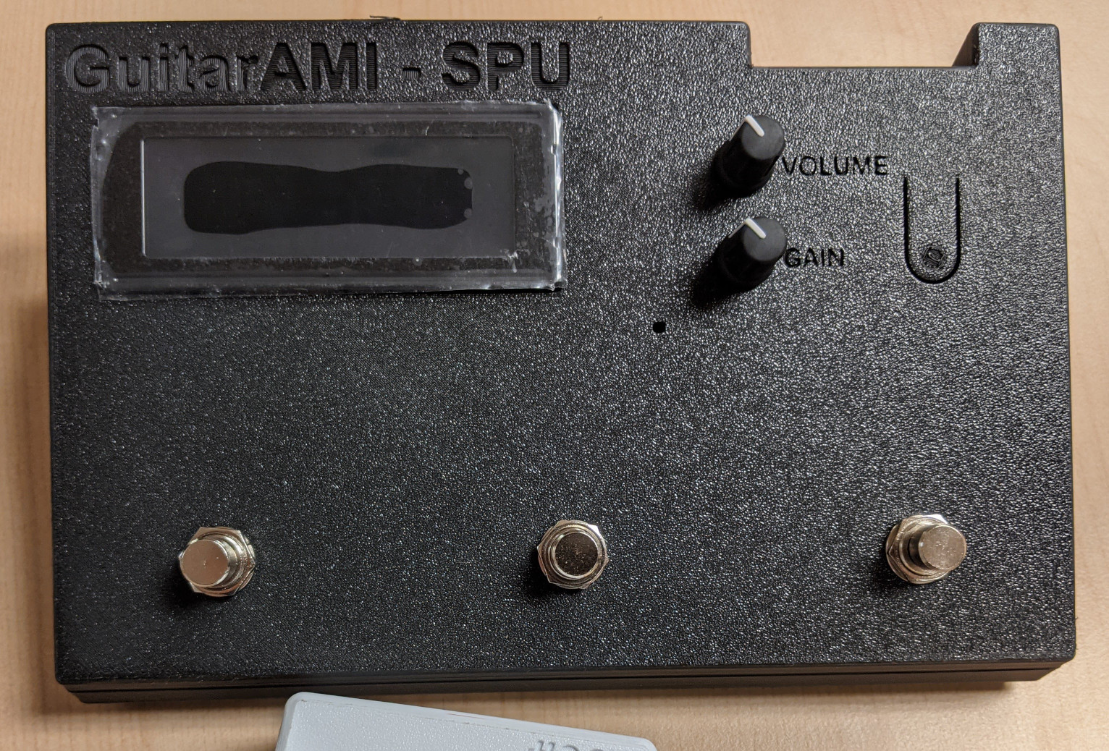
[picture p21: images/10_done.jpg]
Done!


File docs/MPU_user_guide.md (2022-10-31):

# GuitarAMI Processing Unit (MPU) user guide

MPUs

- [GuitarAMI Processing Unit (MPU) user guide](#guitarami-processing-unit-mpu-user-guide)
  - [Overview](#overview)
  - [Configuring the MPU behavior](#configuring-the-mpu-behavior)
    - [Accessing the MPU](#accessing-the-mpu)
    - [uploading SuperCollider and Pure Data patches](#uploading-supercollider-and-pure-data-patches)
  - [Information about audio interfaces](#information-about-audio-interfaces)
  - [Information](#information)

## Overview

This user guide describes the GuitarAMI MPU usage, however, the software aspects of this guide are valid for any Raspberry Pi-based MPU, including MPUs set to use external audio interfaces.

The MPU is fully hackeable and runs a customized version of the [Raspberry Pi OS](https://www.raspberrypi.com/software/).

The GuitarAMI MPU overview:

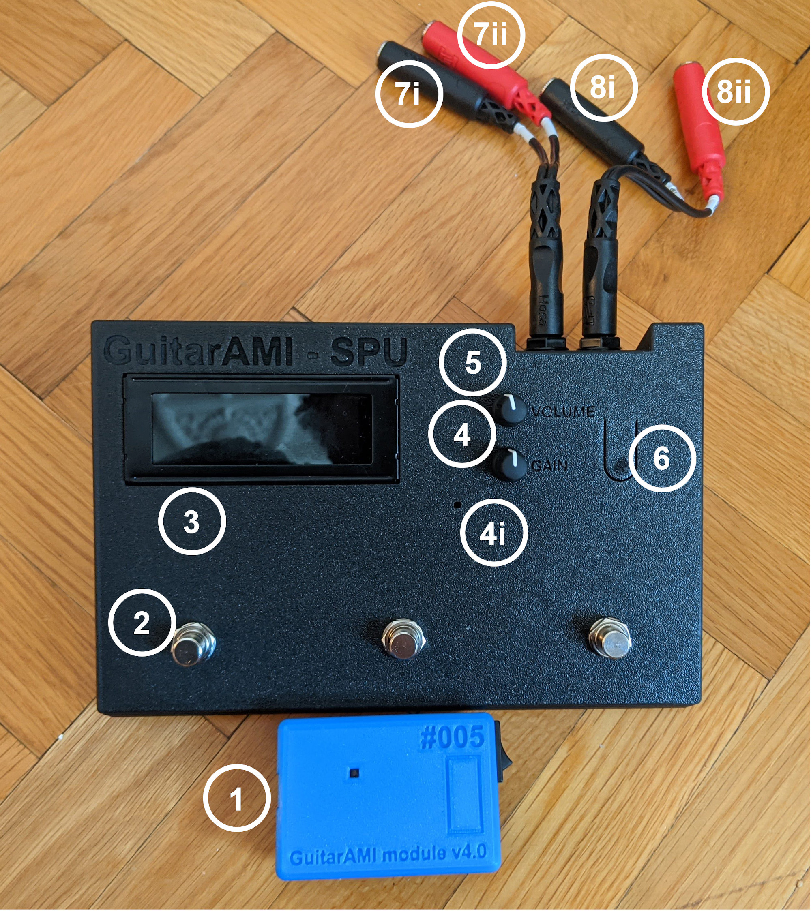
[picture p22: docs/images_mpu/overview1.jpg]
Overview


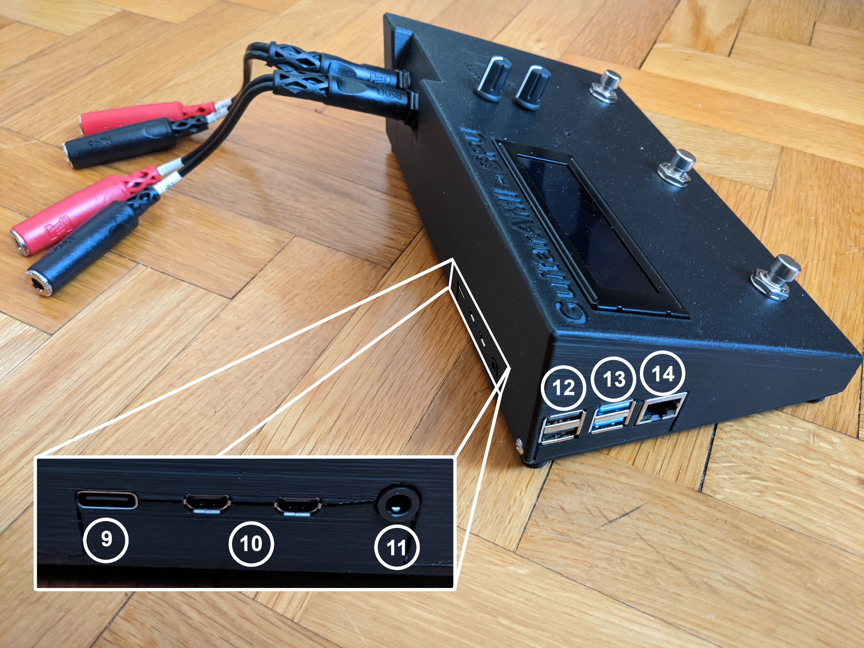
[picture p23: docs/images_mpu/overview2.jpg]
Overview_2 Overview 2


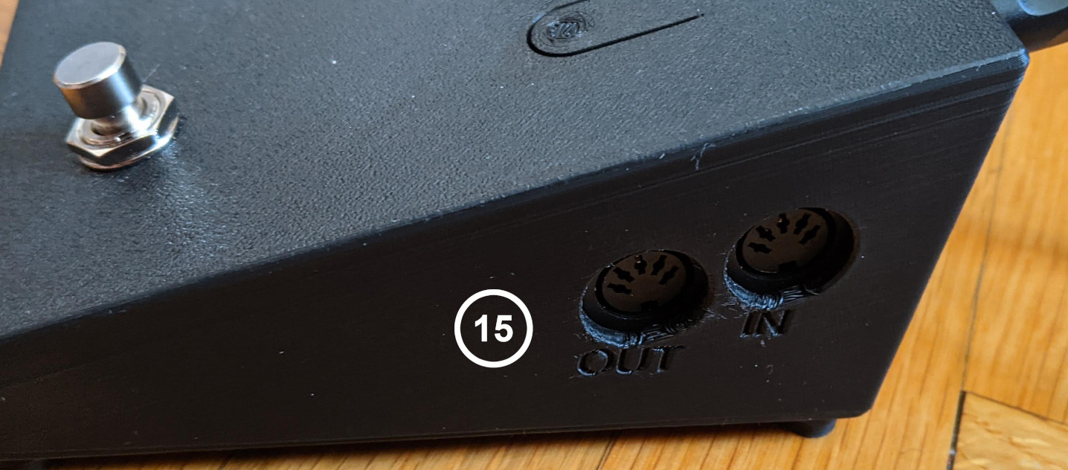
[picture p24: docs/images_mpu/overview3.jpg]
Overview_3 Overview 3


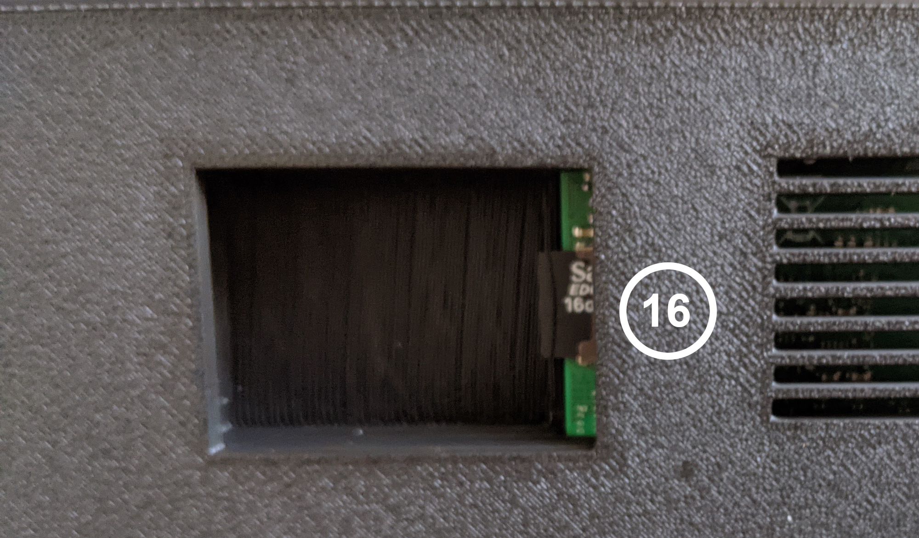
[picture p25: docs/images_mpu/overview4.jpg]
Overview_4 Overview 4


1. GuitarAMI module (for reference)
2. Foot switches
3. Display
4. Gain
    1. LED clip indicator
5. Volume
6. Interface button
7. Audio INs
    1. Left (mono) input (back), equivalent to Audio IN 0 in SuperCollider
    1. Right input (red), equivalent to Audio IN 1 in SuperCollider
8. Audio OUTs
    1. Left (mono) output (back), equivalent to Audio OUT 0 in SuperCollider
    1. Right output (red), equivalent to Audio OUT 1 in SuperCollider
9. Power supply (USB-C, 5V, min 3A)
10. Micro HDMI ports
11. Audio + video composite 3.5 mm jack
12. USB 2.0 ports
13. USB 3.0 ports
14. Gigabit Ethernet port
15. MIDI IN / OUT
16. micro-SD slot

The GuitarAMI version of the MPU also has a built-in LCD display:

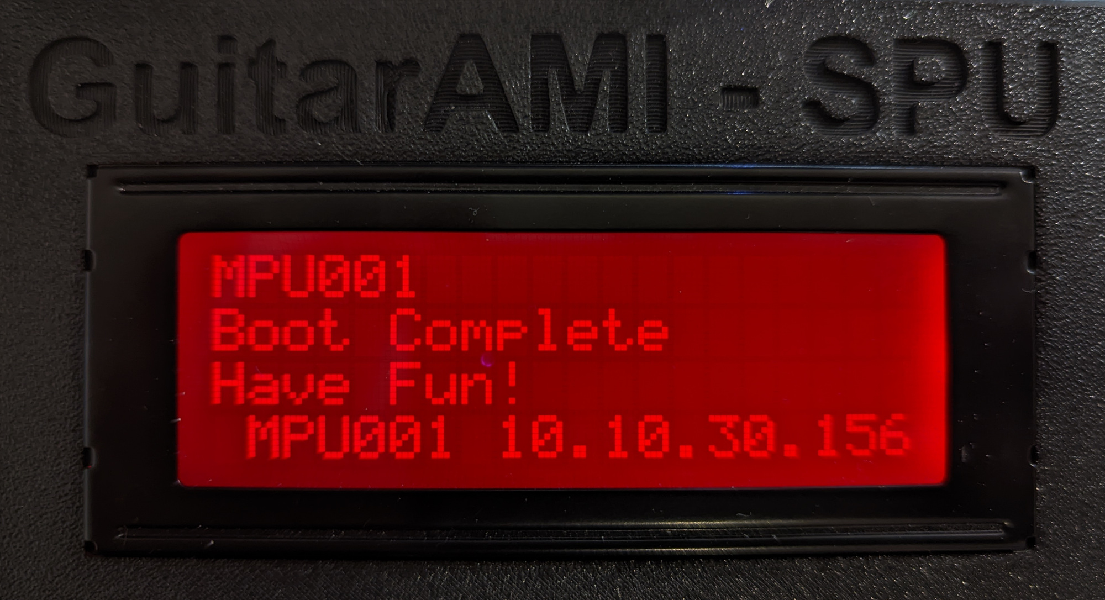
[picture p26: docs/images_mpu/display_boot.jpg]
Boot MPU boot


The display shows when the MPU finishes the booting process and provides visual feedback according to the program. The first three lines can be used freely, but the 4th line is reserved for system information:

The fourth line indicates **MPU ID**** and **ethernet IP address**.
The ID can be used to access the MPU through SSH, VNC, and VNC-over-browser.
The IP address can be used to interact with the MPU if the devices are connected through ethernet.
If using the MPU's access point (hotspot), you can use the Wi-Fi IP 192.168.5.1, configured by default.
It is also possible to change the IP address using a script located at `~/sources/MPU/scripts/chande_ipblock.sh`.

The LCD and status services come disabled by default. You can enable them with the command `sudo systemctl enable --now lcd.service status.service`.

For users connecting [Puara](https://github.com/Puara)-compatible devices, it is also advisable to have the module battery level indicated on the screen.
This information, and any other visual feedback, needs to be manually added using SuperCollider, Pure Data, or any software/language able to send OSC messages to the LCD.

## Configuring the MPU behavior

Before trying to access the MPU configuration options:

- Make sure you are in the same network as your MPU
- Connect to the **MPUXXX** network (replace XXX with your MPU's ID number). The default password is `mappings`

You can:

- Enable or disable the SuperCollider service using the command `systemctl --user enable supercollider.service`
- Enable or disable the Pure Data service using the command `sudo systemctl enable puredata.service`

Both services will run automatically on boot after being enabled and will look for `~/Documents/default.scd` and `~/Documents/default.pd` respectively.
If those files are not present, the service will disable itself until the next boot.

### Accessing the MPU

Once you connect to the MPU network, either using the AP or Ethernet cable (connect both the MPU and your computer in the same network), you can access the device using:

- VNC and VNC-over-browser with the address `mpu001.local` (change the MPU's ID accordingly)
- SSH (with or without X11-Forwarding) using `ssh -X mpu@mpu001.local` (change the MPU's ID accordingly)

For both cases, the user is **mpu** and default password **mappings**.

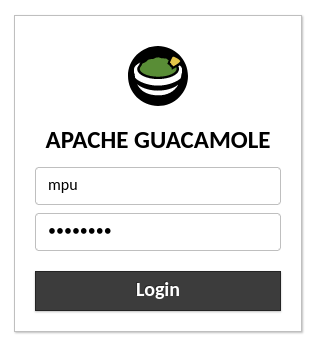
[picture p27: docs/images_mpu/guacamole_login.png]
Guacamole login screen


Once logged in, you'll see the main MPU's window:

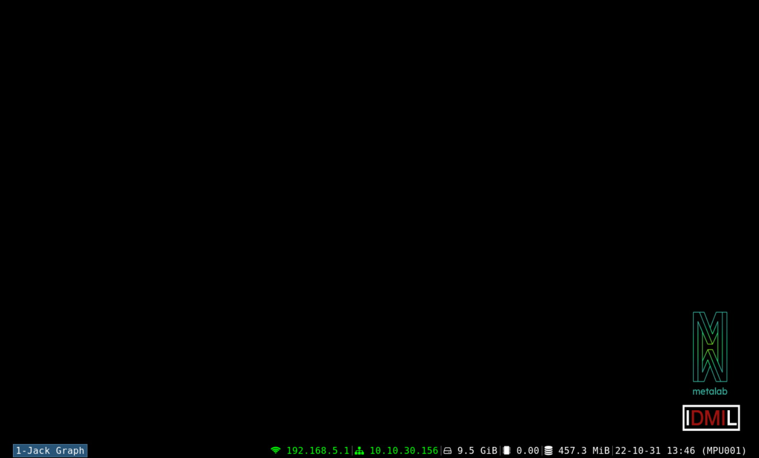
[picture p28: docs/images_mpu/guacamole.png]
VNC-over-browser


The status bar will provide some useful information:

- Wi-Fi IP address
- Ethernet IP address
- Free disk (microSD card) space
- load average (1 min)
- used RAM
- date
- MPU's name/ID

To open any application, you can use `Alt+D` and type the name of the software, e.g. `puredata` or `scide` (for the SuperCollider IDE):

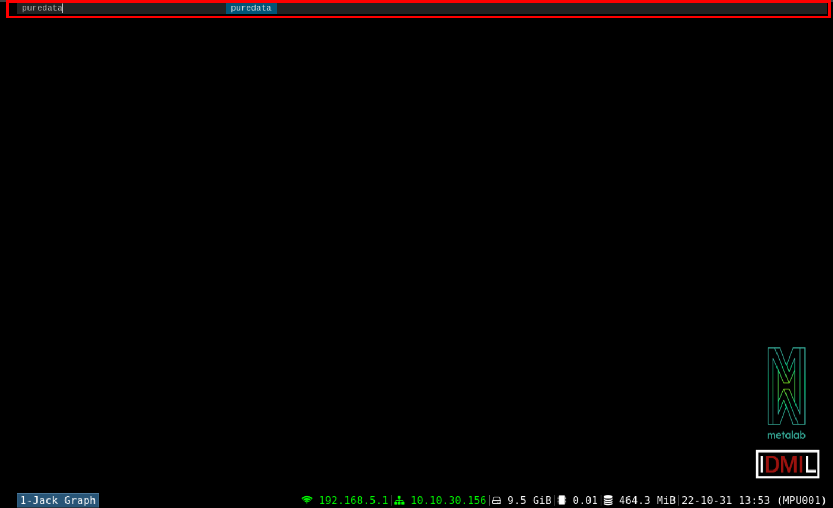
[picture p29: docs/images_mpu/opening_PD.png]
opening_PD


Applications registered will open in their own tabs. New applications will open o the current tab.
To change tabs one can use `Ctrl+0-9`. 

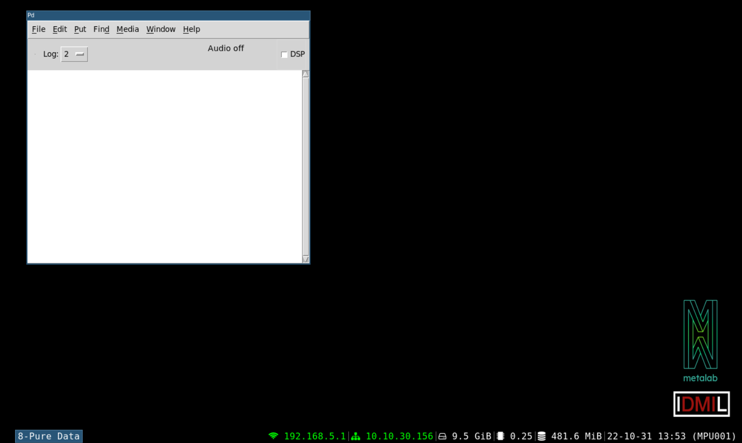
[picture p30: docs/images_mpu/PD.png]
PD


Finally, `Alt+Enter` opens a new terminal window, and most windows can be closed with either `Ctrl+Shift+Q` or a mouse middle click on the bar.

### uploading SuperCollider and Pure Data patches

Sometimes it is useful to program pathces using the laptop and deploy them later to the MPU.
The `~/Documents` folder can be accessed using a shared folder over the network (Samba share).
Windows, Linux, and macOS users should see the folder as soon as they connect to the MPU network.
This folder is password protected.
The user is **mpu** and the password **mappings**. In the picture below, the user can access the folders by clicking on `Connect as...` and entering the credentials.

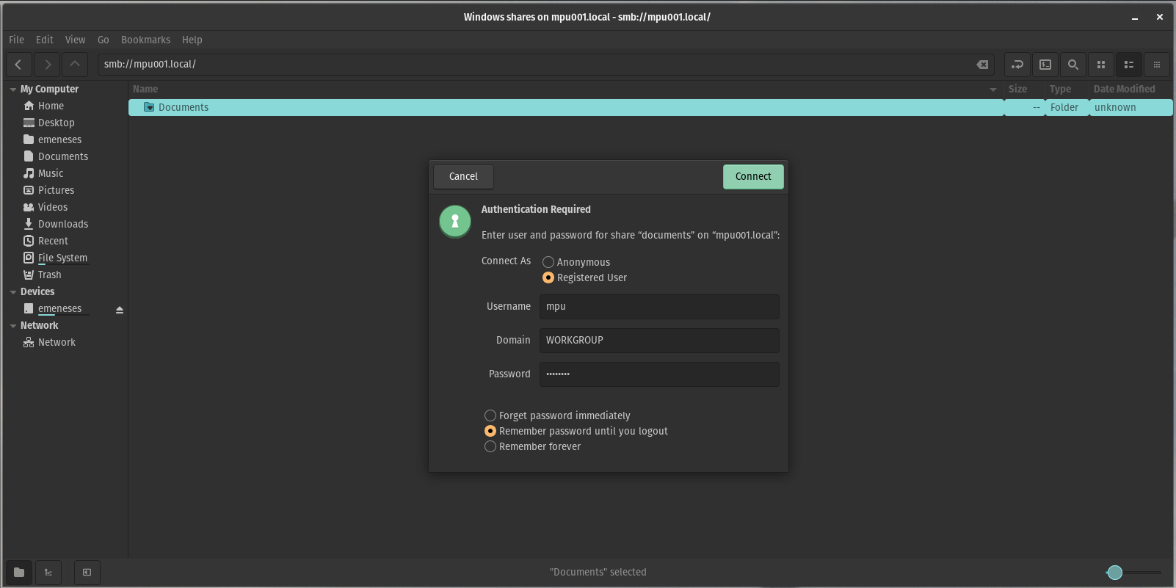
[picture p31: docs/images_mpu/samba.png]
Network Access


## Information about audio interfaces

Internal audio interfaces using I2S should be enable automatically.
We don´t recommend installing the PiSound software as it may conflict with the configured Jack audio service.

For older Fe-Pi audio cards, it may be necessary to enable the interface manually according to the instructions available at [https://fe-pi.com/p/support-and-setup](https://fe-pi.com/p/support-and-setup) (link down in 2021/02/25).

Simply copy and paste/execute the following command:

```bash
sudo sed -i -e 's/Enable audio (loads snd_bcm2835)/Disable audio (loads snd_bcm2835)/ ; s/dtparam=audio=on/dtparam=audio=off\n\n# Enable Fe-Pi\ndtoverlay=fe-pi-audio/' /boot/config.txt
```

## Information

GuitarAMI Sound Processing Unit (MPU) - Raspberry Pi 4B + PiSound

[SAT/Metalab](https://sat.qc.ca/fr/recherche/metalab)

[Input Devices and Music Interaction Laboratory (IDMIL)](http://www.idmil.org/)

[Centre of Interdisciplinary Research In Music Media and Technology (CIRMMT)](http://www.cirmmt.org/)

October 2022 by [Edu Meneses](http://www.edumeneses.com/)

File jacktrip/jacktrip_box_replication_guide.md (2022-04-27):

# JackTrip boxes - replication guide

- [JackTrip boxes - replication guide](#jacktrip-boxes---replication-guide)
  - [BOM](#bom)
  - [Hardware assembly](#hardware-assembly)
  - [Configuring Jack](#configuring-jack)
  - [Setting the server IP for JackTrip client boxes](#setting-the-server-ip-for-jacktrip-client-boxes)

## BOM

To replicate the JackTrip boxes, you'll need:

- 1 Raspberry Pi 4 B 4GB with enclosure
- 1 SD card (min 8GB), and an SD card reader if needed
- 1 power supply compatible with the Raspberry Pi
- 1 audio interface
- 1 USB cable to connect the audio interface
- 1 power supply
- 1 ethernet cable

## Hardware assembly

- Follow the instructions available for the Raspberry Pi enclosure purchased. For the first 2 boxes, the enclosure instructions are available at [https://www.canakit.com/pi-case](https://www.canakit.com/pi-case)
- Flash the JackTrip box image (**jacktripbox.img.gz**) into the SD card using [ApplePiBaker](https://www.tweaking4all.com/hardware/raspberry-pi/applepi-baker-v2/), [balenaEtcher](https://www.balena.io/etcher/), or diskutil (dd).
- Put the SD card on the JackTrip box, connect the audio interface/cables according to the [user guide](jacktrip_box_user_guide.md), and turn on the Raspberry Pi. You can use a monitor and keyboard to control the JackTrip box during setup. It is also possible to connect to the JackTrip box using *ssh*.
- Enter PiSound configuration: `sudo pisound-config`
  - Change Pisound HotSpot settings:
    - ssid: `jacktrip00X` (use MPU's ID)

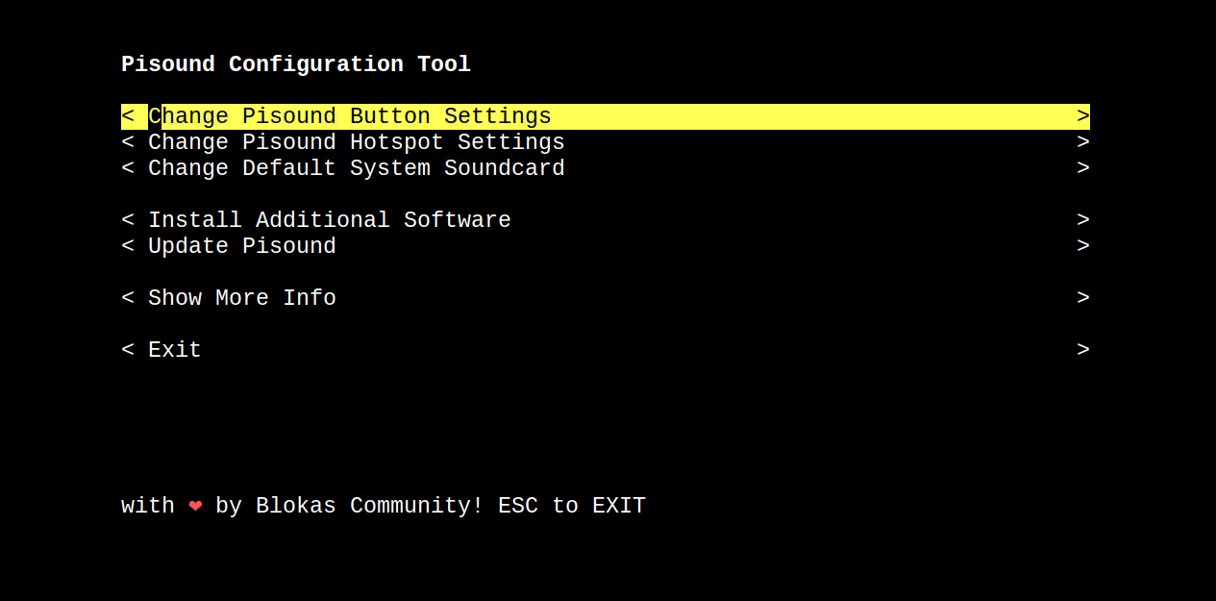
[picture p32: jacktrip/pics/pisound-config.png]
pisound-config

(image source: [PiSound documentation](https://blokas.io/pisound/docs/pisound-config/))

- Enter Raspi-Config: `sudo raspi-config`
  - System options:
    - Hostname: `jacktrip00X` (use chosen ID)

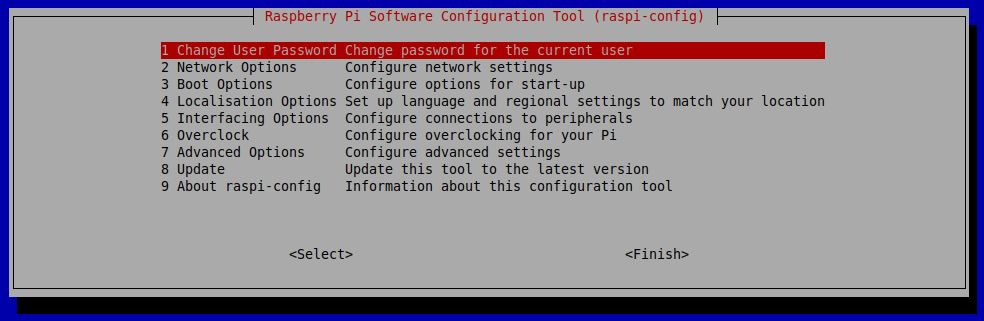
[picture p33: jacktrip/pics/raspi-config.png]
raspi-config

(image source: [Raspberry Pi documentation](https://www.raspberrypi.com/documentation/computers/configuration.html#raspi-config))

## Configuring Jack

If the user wants to replace the audio interface or try different settings, we can run the `patchbox` command and change the Jack audio configuration.

The recommended configuration for the Scarlett Solo is *Sr=48000, bs=128, period=3*. More aggressive configurations can be tested in faster networks, as the Scarlett Solo can use *Sr=96000, bs=128, period=2* locally without any issues.

## Setting the server IP for JackTrip client boxes

- Edit the *jacktrip_client.service* file: `nano ~/.config/systemd/user/jacktrip_client.service`
- Replace the IP at the line `ExecStart=/home/patch/sources/jacktrip/builddir/jacktrip -c 192.168.1.1 --clientname jacktrip_client` for the new IP address
- Save the file (Ctrl+O, then hit ENTER in *nano*) and exit (Ctrl+X in *nano*).
- Update the systemctl daemon: `systemctl --user daemon-reload`
- Restart the service: `systemctl --user restart jacktrip_client.service`
- To check connection (if the server is available and accessible through the given IP): `systemctl --user status jacktrip_client.service`

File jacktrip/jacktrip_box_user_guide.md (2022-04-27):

# JackTrip box - user guide

## Regular use: connect to JackTrip server

To use the **JackTrip box client** at home and connect to the UdeM JackTrip server, you will need the following:

- 1 Raspberry Pi Jacktrip client
- 1 audio interface
- 1 USB-A to USB-c cable
- 1 power supply
- 1 ethernet cable
- microphone, active speakers, and headphones

Follow the connections showered in the picture below:

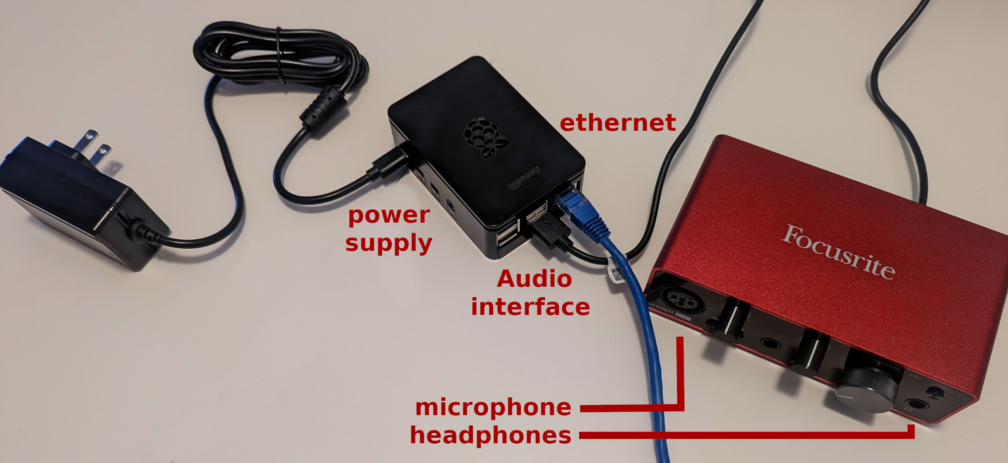
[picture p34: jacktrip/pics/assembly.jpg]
Jacktrip box assembly


Connect the ethernet cable to your router and turn the JackTrip box ON (connect to the power outlet).

After a few seconds, you should be automatically connected to the UdeM JackTrip server.

## Latency test

If you're required to assist in a latency test, connect an audio cable between the instrument input and the headphone jack, as shown in the picture below:

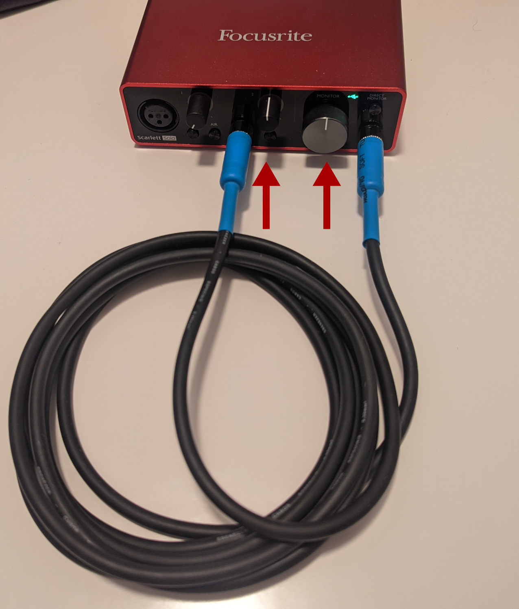
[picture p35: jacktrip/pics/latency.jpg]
Jacktrip latency test assembly


Make sure both the input gain and the monitor volume are set to the "12 o'clock" position (check the red arrows on the image).

An operator at the JackTrip server will launch the latency test and collect the results.

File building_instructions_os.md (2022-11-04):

# Building Instructions - Puara Media Processing Unit

- [Building Instructions - Puara Media Processing Unit](#building-instructions---puara-media-processing-unit)
  - [BOM](#bom)
  - [Prepare SD card](#prepare-sd-card)
  - [First configuration](#first-configuration)
  - [MPU Script](#mpu-script)
    - [Setting the OS](#setting-the-os)
    - [Set RealVNC security scheme](#set-realvnc-security-scheme)
    - [Update OS, install basic apps, and install i3wm as an alternative window manager](#update-os-install-basic-apps-and-install-i3wm-as-an-alternative-window-manager)
    - [Disable the built-in and HDMI audio](#disable-the-built-in-and-hdmi-audio)
    - [Add Metalab's MPA](#add-metalabs-mpa)
    - [Configure AP](#configure-ap)
    - [install Apache Guacamole](#install-apache-guacamole)
    - [Install basic software](#install-basic-software)
    - [Set Jack to start at boot](#set-jack-to-start-at-boot)
    - [Set Pure Data systemd service](#set-pure-data-systemd-service)
    - [Set SuperCollider systemd service](#set-supercollider-systemd-service)
    - [Set up i3wm](#set-up-i3wm)
    - [Adding a service to start JackTrip server](#adding-a-service-to-start-jacktrip-server)
    - [Adding a service to start JackTrip client](#adding-a-service-to-start-jacktrip-client)
    - [Make a systemd service for aj-snapshot](#make-a-systemd-service-for-aj-snapshot)
    - [Install Samba server](#install-samba-server)
    - [Make all systemd services available](#make-all-systemd-services-available)
    - [Optimize boot time](#optimize-boot-time)
    - [Mapping using jack in CLI](#mapping-using-jack-in-cli)
    - [Latency tests](#latency-tests)
    - [Jack available commands](#jack-available-commands)
    - [Finish and rebooting](#finish-and-rebooting)

## BOM

- minimal hardware
  - [Raspberry Pi 4 model B](https://www.raspberrypi.com/products/raspberry-pi-4-model-b/)
  - External audio interface. If using the PiSound refer to [https://blokas.io/pisound](https://blokas.io/pisound) for installation instructions
- software
  - [Custom PREEMPT-RT kernel](RT_kernel.md) (build on 5.10)
  - [Raspberry Pi OS](https://ubuntu.com/download/raspberry-pi)
  - Metalab software (through the [Metalab's MPA](https://gitlab.com/sat-mtl/distribution/mpa-bullseye-arm64-rpi/))

## Prepare SD card

- Download the (Raspberry Pi Imager)[https://www.raspberrypi.com/software/]
- Flash the Raspberry Pi OS 64 bits into the microSD card. Use the configuration tool to set:
  - Enable ssh
  - set hostname: mpuXXX (replace XXX with the MPU's ID)
  - set user and password (mpu/mappings)
  - insert WiFi credential if needed
- OPTIONAL: if you plan to access your Rpi headlessly, you also need to ensure ssh is enabled on first boot by navigating to the `boot` partition on the microSD card and creating an empty file called **ssh** (e.g., use `touch ssh` in the command line)
- Insert the microSD card in the Rpi and turn it on

## First configuration

- First configuration for the Raspberry Pi. Information on available ***raspi-config no interactive*** commands can be found at https://github.com/raspberrypi-ui/rc_gui/blob/master/src/rc_gui.c

- Ssh (with the X11-Forwarding flag) to the Rpi: `ssh -X mpu@<ip_address>` or `ssh -X mpu@mpuXXX.local`. The Rpi might take a longer time to be available to ssh during the first boot as it is expanding the filesystem. Obs: it is important to enable X11 forwarding as the installed SuperCollider version needs it to run sclang and install SATIE. 
- Copy and paste the code block below to automatically run the [MPU Script](#mpu-script) routine:

```bash
sudo apt install -y tmux git liblo-tools
mkdir ~/sources && cd ~/sources &&\
git clone https://github.com/Puara/MPU.git &&\
cd ~/sources/MPU/scripts &&\
sudo chmod +x building_script.sh rename_mpu.sh change_ipblock.sh &&\
./building_script.sh &&\
./run_script.sh
```

- You will be asked to choose an MPU ID before the script starts preparing the OS.

- The next section describes all steps automatically executed by the commands presented above. If you copied and pasted the commands above, you don't need to follow the following instructions and your MPU will be automatically set.
 
## MPU Script

### Setting the OS

```bash
sudo raspi-config nonint do_vnc 0
sudo raspi-config nonint do_vnc_resolution 1920x1080
sudo raspi-config nonint do_memory_split 256
sudo raspi-config nonint do_wifi_country CA
sudo raspi-config --expand-rootfs
```

### Set RealVNC security scheme

```bash
echo -e "mappings\nmappings" | sudo vncpasswd -service
sudo sed -i '$a Authentication=VncAuth' /root/.vnc/config.d/vncserver-x11
```

- The password set by default is `mappings`

### Update OS, install basic apps, and install i3wm as an alternative window manager

```bash
sudo apt update -y && sudo apt upgrade -y
sudo apt install -y i3 i3blocks htop vim feh x11-utils git-lfs fonts-font-awesome jacktrip
```

- Update desktop alternatives and select i3 as the default window manager:

```bash
sudo update-alternatives --install /usr/bin/x-session-manager x-session-manager /usr/bin/i3 60
echo "2" | sudo update-alternatives --config x-session-manager
```

### Disable the built-in and HDMI audio

```bash
sudo sed -i -e 's/Enable audio (loads snd_bcm2835)/Disable audio (snd_bcm2835)/ ; s/dtparam=audio=on/dtparam=audio=off/ ; s/dtoverlay=vc4-kms-v3d/dtoverlay=vc4-kms-v3d,noaudio/' /boot/config.txt
```

### Add Metalab's MPA

```bash
sudo apt install -y coreutils wget && \
wget -qO - https://sat-mtl.gitlab.io/distribution/mpa-bullseye-arm64-rpi/sat-metalab-mpa-keyring.gpg \
    | gpg --dearmor \
    | sudo dd of=/usr/share/keyrings/sat-metalab-mpa-keyring.gpg && \
echo 'deb [ arch=arm64, signed-by=/usr/share/keyrings/sat-metalab-mpa-keyring.gpg ] https://sat-mtl.gitlab.io/distribution/mpa-bullseye-arm64-rpi/debs/ sat-metalab main' \
    | sudo tee /etc/apt/sources.list.d/sat-metalab-mpa.list && \
sudo apt update &&\
sudo apt upgrade -y
```

### Configure AP

- Install dependencies:

```bash
sudo apt install -y dnsmasq hostapd
```

- Create the hostapd config file:

```bash
cat <<- "EOF" | sudo tee /etc/hostapd/hostapd.conf
interface=wlan0
driver=nl80211
ssid=MPUXXX
hw_mode=g
channel=6
macaddr_acl=0
auth_algs=1
ignore_broadcast_ssid=0
wpa=2
wpa_passphrase=mappings
wpa_key_mgmt=WPA-PSK
wpa_pairwise=TKIP
rsn_pairwise=CCMP
EOF
```

- Configure a static IP for the wlan0 interface:

```bash
sudo sed -i -e 's/hostname/mpuXXX/' -e '$a\\ninterface wlan0\n    static ip_address=192.168.5.1/24\n    nohook wpa_supplicant\n    #denyinterfaces eth0\n    #denyinterfaces wlan0\n' /etc/dhcpcd.conf
```

- Set hostapd to read the config file:

```bash
sudo sed -i 's,#DAEMON_CONF="",DAEMON_CONF="/etc/hostapd/hostapd.conf",' /etc/default/hostapd
```

- Start the hostapd service:

```bash
sudo systemctl unmask hostapd &&
sudo systemctl enable hostapd &&
sudo systemctl start hostapd
sudo DEBIAN_FRONTEND=noninteractive apt install -y netfilter-persistent iptables-persistent
```

- Start configuring the dnsmasq service

```bash
sudo unlink /etc/resolv.conf &&
echo nameserver 8.8.8.8 | sudo tee /etc/resolv.conf &&
cat <<- "EOF" | sudo tee /etc/dnsmasq.conf
interface=wlan0
dhcp-range=192.168.5.2,192.168.5.20,255.255.255.0,24h
EOF
```

- Modify `/lib/systemd/system/dnsmasq.service` to launch after network get ready:

```bash
sudo sed -i '0,/^\s*$/'\
's//After=network-online.target\nWants=network-online.target\n/' \
/lib/systemd/system/dnsmasq.service
```

- To prevent a long waiting time during boot, edit `/lib/systemd/system/systemd-networkd-wait-online.service`:

```bash
sudo sed -i '\,ExecStart=/lib/systemd/systemd-networkd-wait-online, s,$, --any,' /lib/systemd/system/systemd-networkd-wait-online.service
sudo systemctl daemon-reload
```

### install Apache Guacamole

- More info at https://guacamole.apache.org
- Reference: [Guacamole manual](https://guacamole.apache.org/doc/gug/)

- Install dependencies:

```bash
sudo apt install -y libcairo2-dev libpng-dev libjpeg62-turbo-dev libtool-bin libossp-uuid-dev libavcodec-dev libavformat-dev libavutil-dev libswscale-dev freerdp2-dev libpango1.0-dev libssh2-1-dev libtelnet-dev libvncserver-dev libwebsockets-dev libpulse-dev libssl-dev libvorbis-dev libwebp-dev jetty9
```

- Clone git and install (set for version 1.4.0):

```bash
cd ~/sources
wget -O guacamole-server-1.4.0.tar.gz "https://apache.org/dyn/closer.lua/guacamole/1.4.0/source/guacamole-server-1.4.0.tar.gz?action=download"
tar -xzf guacamole-server-1.4.0.tar.gz
cd guacamole-server-1.4.0
autoreconf -fi
./configure
make
sudo make install
sudo ldconfig
cd ~/sources
wget -O guacamole.war "https://apache.org/dyn/closer.lua/guacamole/1.4.0/binary/guacamole-1.4.0.war?action=download"
sudo cp ~/sources/guacamole.war /var/lib/jetty9/webapps/guacamole.war
```

- Create the Guacamole home:

```bash
sudo mkdir /etc/guacamole
```

- Create `user-mapping.xml`

```bash
cat <<- "EOF" | sudo tee /etc/guacamole/user-mapping.xml
<user-mapping>
    <authorize
    username="mpu"
    password="mappings">
        <connection name="MPU">
        <protocol>vnc</protocol>
        <param name="hostname">localhost</param>
        <param name="port">5900</param>
        <param name="password">mappings</param>
        </connection>
    </authorize>
</user-mapping>
EOF
```

```bash
sudo mv /var/lib/jetty9/webapps/root /var/lib/jetty9/webapps/root-OLD
sudo mv /var/lib/jetty9/webapps/guacamole.war /var/lib/jetty9/webapps/root.war
```

- Change Guacamole login screen:

```bash
sudo mkdir /etc/guacamole/extensions
sudo cp ~/sources/MPU/mpu.jar /etc/guacamole/extensions/mpu.jar
```

- Configure addresses

```bash
sudo apt install apache2 -y
sudo a2enmod proxy
sudo a2enmod proxy_http
sudo a2enmod proxy_balancer
sudo a2enmod lbmethod_byrequests
sudo a2enmod rewrite
sudo mv /etc/apache2/sites-available/000-default.conf /etc/apache2/sites-available/000-default.conf.bak
```

```bash
cat <<- "EOF" | sudo tee /etc/apache2/sites-available/000-default.conf
<VirtualHost *:80>

    RewriteEngine on
    RewriteRule ^/webmapper$ /webmapper/ [R]

    ProxyRequests Off
    ProxyPreserveHost On

    ProxyPass /webmapper http://127.0.0.1:50000
    ProxyPassReverse /webmapper http://127.0.0.1:50000
    ProxyPass / http://127.0.0.1:8080/
    ProxyPassReverse / http://127.0.0.1:8080/

</VirtualHost>
EOF
```

```bash
sudo systemctl restart apache2
```

- Set guacd to start at boot

```bash
cat <<- "EOF" | sudo tee /lib/systemd/system/guacd.service
[Unit]
Description=Run Guacamole server
After=multi-user.target

[Service]
Type=idle
Restart=always
User=mpu
ExecStart=/usr/local/sbin/guacd -b 127.0.0.1 -f

[Install]
WantedBy=default.target
EOF
sudo systemctl daemon-reload
sudo systemctl enable guacd
sudo systemctl start guacd
```

### Install basic software

- Installing SuperCollider, SC3-Plugins, jackd2 (if needed):

```bash
sudo apt install -y supercollider sc3-plugins libmapper python3-netifaces webmapper jackd2 qjackctl puredata aj-snapshot
```

- Installing SATIE:

```bash
cd ~/sources
git clone https://gitlab.com/sat-mtl/tools/satie/satie.git
echo "Quarks.install(\"SC-HOA\");Quarks.install(\"~/sources/satie\")" | sclang
```

### Set Jack to start at boot

- Add a dbus security policy:

```bash
cat <<- "EOF" | sudo tee /etc/dbus-1/system.conf
<policy user="micah">
     <allow own="org.freedesktop.ReserveDevice1.Audio0"/>
     <allow own="org.freedesktop.ReserveDevice1.Audio1"/>
</policy>
EOF
```

- Add path to environment:

```bash
cat <<- "EOF" | sudo tee /etc/environment
export DBUS_SESSION_BUS_ADDRESS=unix:path=/run/dbus/system_bus_socket
EOF
```

- Create the systemd service file:

```bash
cat <<- "EOF" | sudo tee /lib/systemd/system/jackaudio.service
[Unit]
Description=JACK Audio
After=sound.target

[Service]
LimitRTPRIO=infinity
LimitMEMLOCK=infinity
User=mpu
Environment="JACK_NO_AUDIO_RESERVATION=1"
ExecStart=/usr/bin/jackd -R -P95 -t2000 -dalsa -dhw:1 -p256 -n2 -r48000 -s &

[Install]
WantedBy=multi-user.target
EOF
sudo systemctl daemon-reload
sudo systemctl enable jackaudio.service
```

- Some commands:

- List information and connections on ports: `jack_lsp -c`
- Connect ports: `jack_connect [ -s | --server servername ] [-h | --help ] port1 port2` (The exit status is zero if successful, 1 otherwise)
- Disconnect ports: `jack_disconnect [ -s | --server servername ] [ -h | --help ] port1 port2`

### Set Pure Data systemd service

```bash
cat <<- "EOF" | sudo tee /lib/systemd/system/puredata.service
[Unit]
Description=Pure Data
After=sound.target jackaudio.service
ConditionPathExists=/home/mpu/Documents/default.pd

[Service]
LimitRTPRIO=infinity
LimitMEMLOCK=infinity
User=mpu
ExecStart=pd -nogui -noprefs -rt -jack -inchannels 2 -outchannels 2 ~/Documents/default.pd

[Install]
WantedBy=multi-user.target
EOF
sudo systemctl daemon-reload
sudo systemctl enable puredata.service
sudo systemctl start puredata.service
```

### Set SuperCollider systemd service

- OBS: starting as a user service to allow required access

```bash
mkdir -p ~/.config/systemd/user
cat <<- "EOF" | tee ~/.config/systemd/user/supercollider.service
[Unit]
Description=SuperCollider
After=multi-user.target
ConditionPathExists=/home/mpu/Documents/default.scd

[Service]
Type=idle
Restart=always
ExecStart=sclang -D /home/mpu/Documents/default.scd

[Install]
WantedBy=default.target
EOF
sudo chmod 644 ~/.config/systemd/user/supercollider.service
systemctl --user daemon-reload
systemctl --user enable --now supercollider.service
```

### Set up i3wm

- Copy i3_config to `~/.config/i3` and rename to `config`:
- Copy i3status.conf to `/etc`:

```bash
mkdir ~/.config/i3
cp ~/sources/MPU/i3_config ~/.config/i3/config
sudo cp ~/sources/MPU/i3status.conf /etc/i3status.conf
cp ~/sources/MPU/wallpaper.png ~/Pictures/wallpaper.png
sudo sed -i -e "s/MPU/MPUXXX/" /etc/i3status.conf
```

- OBS: for checking Font Awesome: https://fontawesome.com/v5/cheatsheet

### Adding a service to start JackTrip server

- OBS: client name is the name of the other machine

```bash
cat <<- "EOF" | sudo tee /lib/systemd/system/jacktrip_server.service
[Unit]
Description=Run JackTrip server
After=multi-user.target

[Service]
Type=idle
Restart=always
ExecStart=~/sources/jacktrip/builddir/jacktrip -s --clientname jacktrip_client

[Install]
WantedBy=default.target
EOF
```

- To enable the service at boot: `sudo systemctl enable jacktrip_server.service`

### Adding a service to start JackTrip client

- Replace the IP address for the server IP.

```bash
cat <<- "EOF" | sudo tee /lib/systemd/system/jacktrip_client.service
[Unit]
Description=Run JackTrip client
After=multi-user.target

[Service]
Type=idle
Restart=always
ExecStart=~/sources/jacktrip/builddir/jacktrip -c 192.168.5.1 --clientname jacktrip_client

[Install]
WantedBy=default.target
EOF
```

- If you want to enable the client, disable the service and run `sudo systemctl enable jacktrip_client.service`
- To manually use as a client with IP address: `./jacktrip -c [xxx.xx.xxx.xxx]`, or with name: `./jacktrip -c mpuXXX.local`

### Make a systemd service for aj-snapshot

- More info at [http://aj-snapshot.sourceforge.net/](http://aj-snapshot.sourceforge.net/)

- To create a snapshot: `aj-snapshot -f ~/Documents/default.connections`
- To remove all Jack connections: `aj-snapshot -xj`
- To save connections: `sudo aj-snapshot -f ~/Documents/default.connections`
- To restore connections: `sudo aj-snapshot -r ~/Documents/default.connections`

- Set custom Jack connections to load at boot:

```bash
cat <<- "EOF" | sudo tee /lib/systemd/system/ajsnapshot.service
[Unit]
Description=AJ-Snapshot
After=sound.target jackaudio.service
ConditionPathExists=/home/mpu/Documents/default.connections

[Service]
Type=idle
Restart=always
User=mpu
ExecStart=/usr/local/bin/aj-snapshot -d ~/Documents/default.connections

[Install]
WantedBy=multi-user.target
EOF
sudo systemctl daemon-reload
sudo systemctl enable ajsnapshot.service
sudo systemctl start ajsnapshot.service
```

- If you want to save a ajsnapshot file run: `aj-snapshot -f ~/Documents/default.connections`

### Install Samba server

- OBS: Choose *No* if asked **Modify smb.conf to use WINS settings from DHCP?**

```bash
sudo apt install -y samba
sudo systemctl stop smbd.service
sudo mv /etc/samba/smb.conf /etc/samba/smb.conf.orig
```

- Create Samba configuration file and set the user:

```bash
cat <<- "EOF" | sudo tee /etc/samba/smb.conf
[global]
        server string = MPUXXX
        server role = standalone server
        interfaces = lo eth0 wlan0
        bind interfaces only = no
        smb ports = 445
        log file = /var/log/samba/smb.log
        max log size = 10000
        map to guest = bad user

[Documents]
        path = "/home/mpu/Documents"
        read only = no
        browsable = yes
        valid users = mpu
        vfs objects = recycle
        recycle:repository = .recycle
        recycle:touch = Yes
        recycle:keeptree = Yes
        recycle:versions = Yes
        recycle:noversions = *.tmp,*.temp,*.o,*.obj,*.TMP,*.TEMP
        recycle:exclude = *.tmp,*.temp,*.o,*.obj,*.TMP,*.TEMP
        recycle:excludedir = /.recycle,/tmp,/temp,/TMP,/TEMP

EOF
(echo mappings; echo mappings) | sudo smbpasswd -a mpu
sudo smbpasswd -e mpu
sudo systemctl start smbd.service
sudo systemctl enable smbd.service
```

### Make all systemd services available

```bash
sudo systemctl daemon-reload
```

### Optimize boot time

- Disable bluetooth and hciuart:

```bash
sudo sed  -i -e '$a\\n# Disable bluetooth (fast boot time)\ndtoverlay=disable-bt' /boot/config.txt
sudo systemctl disable hciuart.service
```

- Disable Modem Manager service. If using radio communication (2g, 3g, 4g) or USB devices that use radio, re-enabling it might be needed

```bash
sudo systemctl disable ModemManager.service
```

- Disable Samba NetBIOS name server daemon. If NETBIOS is needed, re-enable it

```bash
sudo systemctl disable nmbd.service
```

### Mapping using jack in CLI

- Check available devices: `cat /proc/asound/cards`. If you have multiple devices available, can call them by name
- Lists jack available ports: `jack_lsp`
- List information and connections on ports: `jack_lsp -c` or `jack_lsp -A`
- Connect ports: `jack_connect [ -s | --server servername ] [-h | --help ] port1 port2` (The exit status is zero if successful, 1 otherwise)
- Disconnect ports: `jack_disconnect [ -s | --server servername ] [ -h | --help ] port1 port2`

### Latency tests

- Make sure JackTrip is running.

- Connect the necessary audio cable to create a loopback on the client's audio interface (audio OUT -> audio IN)
- For the loopback (same interface test): `jack_delay -I system:capture_2 -O system:playback_2`
- run the test: `jack_delay -O jacktrip_client.local:send_2 -I jacktrip_client.local:receive_2`

### Jack available commands

- To get a list on the computer, type **jack** and hit *Tab*

|command |command |command |command |command |
|---|---|---|---|---|
| jack_alias | jack_bufsize | jack_capture | jack_capture_gui | jack_connect |
| jackdbus | jack_disconnect | jack-dl | jack-dssi-host | jack_evmon |
| jack_load | jack_lsp | jack_metro | jack_midi_dump | jack_midi_latency_test |
| jack_net_master | jack_net_slave | jack_netsource | jack-osc | jack-play |
| jack_samplerate | jack-scope | jack_server_control | jack_session_notify | jack_showtime |
| jack_thru | jack_transport | jack-transport | jack-udp | jack_unload |
| jack_control | jack_cpu | jack_cpu_load | jackd | jack_wait |
| jack_freewheel  | jack_iodelay | jack-keyboard | jack_latent_client  | jack_midiseq |
| jack_midisine | jack_monitor_client | jack_multiple_metro | jack-plumbing |
| jack-rack | jack_rec | jack-record | jack_test |
| jack_simdtests  | jack_simple_client  | jack_simple_session_client | jack_zombie |

- To check Jack logs: `sudo journalctl -u jack.service`

### Finish and rebooting

```bash
echo "Build done!"
echo
echo "rebooting..."
echo
sudo reboot
```

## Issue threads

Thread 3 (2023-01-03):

Feature request: forward packets between WiFi and Ethernet

p42ul, 2023-01-03:
Recently, I used the MPU in performance with three [T-Sticks](https://github.com/IDMIL/T-Stick/).

The three T-Sticks connected to the MPU via its WiFi hotspot, and the MPU connected to a laptop via ethernet. Our goal was to use the MPU as a WiFi hotspot that would forward packets to the laptop. Unfortunately, this is currently not possible, as the network interfaces on the MPU do not communicate with one another.

It would be useful to have packet forwarding be the default behavior, and this could most likely be achieved using a configuration like the one described here: https://superuser.com/questions/1715612/how-to-properly-forward-tcp-and-udp-traffic-between-interfaces-using-iptables.

edumeneses, 2023-01-19:
Thanks for this issue

This is more of a (hidden) bug than a feature request. The SPU used to work like that, and somehow the config we used got broken after Raspberry Pi OS rebranding. I left it out of the [building instructions](https://github.com/Puara/MPU/blob/main/building_instructions_os.md) to avoid confusion, but I plan to get back to it when I have some time. Some [internet bridge tutorials online](https://www.elementzonline.com/blog/sharing-or-bridging-internet-to-ethernet-from-wifi-raspberry-pI) might be helpful.

If you hack the T-Tree into forwarding packages between interfaces, please let me know, and we can port the solution to the MPU. Otherwise, I'll try to get back on that after wrapping up the [NVIDIA Jetson MPU](https://gitlab.com/sat-mtl/distribution/jetson-images).

edumeneses, 2024-02-19:
We are closing this issue here as we will migrate the OS part of the MPU to a different project. We will check traffic forwarding by then.

Closed 2024-02-19.

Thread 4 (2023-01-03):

Feature request: Enable AP+STA mode

p42ul, 2023-01-03:
Currently, the MPU ships in AP mode, allowing wireless clients to connect to it but not allowing the MPU to connect to the WAN.

I suggest that the MPU be put by default in AP+STA mode, allowing it simultaneously to act as a WiFi hotspot and to connect to a wireless network, allowing for WAN access.

This would be useful in a performance context if, for example, you had audience members who wished to participate using a webapp, but didn't want to connect to a separate WiFi network. WAN traffic from the audience members could be routed to the MPU, while also allowing instruments (such as the T-Stick) to connect to the access point afforded by the MPU.

One tutorial for doing this on Raspberry Pi can be found here: https://docs.raspap.com/ap-sta/.

edumeneses, 2023-01-19:
That's indeed useful, but I don't know how reliable the WiFi module is in dual mode. I remembered trying this in the past with poor results (intermittent disconnections, unreliable signal). I have to run some tests before implementing it.

Regardless, if reliable interaction using WiFi is required, I usually suggest a dedicated router that provides a stable and stronger signal.

edumeneses, 2024-02-19:
I will close this issue as the OS part of the MPU will migrate soon to another project. We will explore solutions of AP/STA modes then.

Closed 2024-02-19.

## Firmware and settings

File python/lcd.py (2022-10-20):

# Python code to drive the LCD
# Edu Meneses, 2021, IDMIL, CIRMMT, McGill University

# The wiring for the LCD is as follows (SPU with PiSound):
#
# LCD pin    Rpi4 BOARD pin  function
# 1          GND             GND
# 2          5V              5V
# 3          5V, GND         Contrast (0-5V), use a potentiometer here: middle leg to LCD pin 3, sides to Rpi pin 2 or 4 (5V) and 14(GND)
# 4          26 (GPIO 7)     RS (Register Select)
# 5          GND             R/W (Read Write) - GROUND THIS PIN
# 6           3 (GPIO 2)     Enable or Strobe
# 7          -               Data Bit 0 - NOT USED
# 8          -               Data Bit 1 - NOT USED
# 9          -               Data Bit 2 - NOT USED
# 10         -               Data Bit 3 - NOT USED
# 11          5 (GPIO  0)    Data Bit 4
# 12          8 (GPIO 14)    Data Bit 5
# 13         16 (GPIO 25)    Data Bit 6
# 14          7 (GPIO  4)    Data Bit 7
# 15         3V3             LCD Backlight 3V3
# 16         GND (optional)  LCD Backlight R GND
# 17         GND (optional)  LCD Backlight G GND
# 18         GND (optional)  LCD Backlight B GND
#
# OBS: on Rpi4:
#    3V3 = pin 1 = pin 17
#    5V  = pin 2 = pin 4
#    GND = pin 6 = pin 9 = pin 14 = pin 20 = pin 25 = pin 30 = pin 34 = pin 39


#import
import RPi.GPIO as GPIO
import time
from threading import Event
import socket
import os
import types
import sys

# Import needed modules from osc4py3
from osc4py3.as_eventloop import *
#from osc4py3.as_allthreads import *
from osc4py3 import oscmethod as osm

# Define GPIO to LCD mapping
LCD_RS = 26
LCD_E  = 3
LCD_D4 = 5
LCD_D5 = 8
LCD_D6 = 16
LCD_D7 = 7
# LCD_VEE = 15 # Contrast

# Define some device constants
LCD_WIDTH = 20 # Maximum characters per line
LCD_CHR = True
LCD_CMD = False

LCD_LINE_1 = 0x80 # LCD RAM address for the 1st line
LCD_LINE_2 = 0xC0 # LCD RAM address for the 2nd line
LCD_LINE_3 = 0x94 # LCD RAM address for the 3rd line
LCD_LINE_4 = 0xD4 # LCD RAM address for the 4th line

# To navigate through columns: LCD_LINE + steps (0 to 15)
LCD_POS = [0, LCD_LINE_1, LCD_LINE_2, LCD_LINE_3, LCD_LINE_4]
LCD_TAM = 20

# Timing constants
E_PULSE = 0.0005
E_DELAY = 0.0005

# Start the OSC "server"
osc_startup()

first_message = False

# Make server channels to receive packets
osc_udp_server("0.0.0.0", 20000, "lcdserver")

def lcd_commands(text, line, column):
    global first_message
    if first_message:
        lcd_byte(0x01,LCD_CMD)
        first_message = False
    LCD_TAM = len(text)
    if text == 'clearall':
        lcd_byte(0x01,LCD_CMD)
    if text == 'clear':
        lcd_string("                    ", LCD_LINE_1)
        lcd_string("                    ", LCD_LINE_2)
        lcd_string("                    ", LCD_LINE_3)
    else:
        if 1 <= line <= 4 and 1 <= column <= LCD_WIDTH:
            pos = LCD_POS[int(line)] + column - 1
            lcd_string(text,int(pos))

# Associate Python functions with message address patterns
osc_method("/lcd", lcd_commands)

def main():
    # Main program block

    GPIO.setwarnings(True)
    GPIO.setmode(GPIO.BOARD)     # Use BOARD GPIO numbers (printed on the Pi)
    GPIO.setup(LCD_E, GPIO.OUT)  # E
    GPIO.setup(LCD_RS, GPIO.OUT) # RS
    GPIO.setup(LCD_D4, GPIO.OUT) # DB4
    GPIO.setup(LCD_D5, GPIO.OUT) # DB5
    GPIO.setup(LCD_D6, GPIO.OUT) # DB6
    GPIO.setup(LCD_D7, GPIO.OUT) # DB7
    # GPIO.setup(LCD_VEE, GPIO.OUT) # Contrast for LCD text

    # Set PWM values for LCD contrast
    # my_pwm=GPIO.PWM(15,100)
    # my_pwm.start(10)
    # my_pwm.ChangeFrequency(1000)
    # my_pwm.ChangeDutyCycle(30)

    # Initialise display
    lcd_init()

    lcd_byte(0x01,LCD_CMD)
    lcd_string("MPUXXX", LCD_LINE_1)
    lcd_string("Booting...",LCD_LINE_3)

    # time.sleep(10.0) # 1 second delay
    lcd_byte(0x01,LCD_CMD)

    lcd_string("MPUXXX", LCD_LINE_1)
    lcd_string("Boot Complete", LCD_LINE_2)
    lcd_string("Have Fun!", LCD_LINE_3)

    while True:
        osc_process()
        time.sleep(0.2) # sane sleep time of 0.1 seconds

def lcd_string(message,pos):
    # Send string to display
    lcd_byte(pos, LCD_CMD)
    for i in range(len(message)):
        lcd_byte(ord(message[i]),LCD_CHR)

def lcd_init():
    # Initialise display
    lcd_byte(0x33,LCD_CMD) # 110011 Initialise
    lcd_byte(0x32,LCD_CMD) # 110010 Initialise
    lcd_byte(0x06,LCD_CMD) # 000110 Cursor move direction
    lcd_byte(0x0C,LCD_CMD) # 001100 Display On,Cursor Off, Blink Off
    lcd_byte(0x28,LCD_CMD) # 101000 Data length, number of lines, font size
    lcd_byte(0x01,LCD_CMD) # 000001 Clear display
    time.sleep(E_DELAY)

def lcd_byte(bits, mode):
    # Send byte to data pins
    # bits = data
    # mode = True  for character
    #        False for command

    GPIO.output(LCD_RS, mode) # RS

    # High bits
    GPIO.output(LCD_D4, False)
    GPIO.output(LCD_D5, False)
    GPIO.output(LCD_D6, False)
    GPIO.output(LCD_D7, False)
    if bits&0x10==0x10:
        GPIO.output(LCD_D4, True)
    if bits&0x20==0x20:
        GPIO.output(LCD_D5, True)
    if bits&0x40==0x40:
        GPIO.output(LCD_D6, True)
    if bits&0x80==0x80:
        GPIO.output(LCD_D7, True)

    # Toggle 'Enable' pin
    lcd_toggle_enable()

    # Low bits
    GPIO.output(LCD_D4, False)
    GPIO.output(LCD_D5, False)
    GPIO.output(LCD_D6, False)
    GPIO.output(LCD_D7, False)
    if bits&0x01==0x01:
        GPIO.output(LCD_D4, True)
    if bits&0x02==0x02:
        GPIO.output(LCD_D5, True)
    if bits&0x04==0x04:
        GPIO.output(LCD_D6, True)
    if bits&0x08==0x08:
        GPIO.output(LCD_D7, True)

    # Toggle 'Enable' pin
    lcd_toggle_enable()

def lcd_toggle_enable():
    # Toggle enable
    time.sleep(E_DELAY)
    GPIO.output(LCD_E, True)
    time.sleep(E_PULSE)
    GPIO.output(LCD_E, False)
    time.sleep(E_DELAY)

if __name__ == '__main__':

    try:
        main()
    except KeyboardInterrupt:
        pass
    finally:
        osc_terminate()
        lcd_byte(0x01, LCD_CMD)
        lcd_string("Goodbye!",LCD_LINE_1)
        # my_pwm=GPIO.PWM(15,100)
        # my_pwm.stop()
        GPIO.cleanup()
        sys.exit(0)

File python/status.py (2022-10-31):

# Python code to update the LCD with SPU info
# Edu Meneses, 2021, IDMIL, CIRMMT, McGill University

# Import needed modules from osc4py3
from osc4py3.as_eventloop import *
from osc4py3 import oscbuildparse
import subprocess
import threading
import sys

# Start the system.
osc_startup()

# Make client channels to send packets.
osc_udp_client("0.0.0.0", 20000, "lcd")

def updateStatus():
    ipAdress = subprocess.getoutput("ip -4 addr show eth0 | grep -oP '(?<=inet\s)\d+(\.\d+){3}'")
    currentHostname = subprocess.getoutput("hostname").upper()
    message = currentHostname+" "+ipAdress
    message = message.rjust(20, ' ')
    if len(message) > 20:
        message = message[3:]
    messageOSC = oscbuildparse.OSCMessage("/lcd", ",sii", [message, 4, 21-len(message)])
    osc_send(messageOSC, "lcd")
    osc_process()
    threading.Timer(30, updateStatus).start() # scheduling event every 30 seconds

updateStatus()

def main():
    while True:
        forever = threading.Event(); forever.wait()


if __name__ == '__main__':

    try:
        main()
    except KeyboardInterrupt:
        pass
    finally:
        osc_terminate()
        sys.exit(0)

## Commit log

2022-04-27 add MPU to Puara framework
2022-05-04 add 3D-print designs
    [SPU_box v5 - Bottom.stl, SPU_box v5 - Top.stl, SPU_box v5 - feet.stl]
2022-10-20 optimize boot, add python code for LCD and buttons
2022-10-24 fix lcd status display when MPU disconects from ethernet
    [status.py]
2022-10-25 replace subnet to avoid ESP32 conflict
